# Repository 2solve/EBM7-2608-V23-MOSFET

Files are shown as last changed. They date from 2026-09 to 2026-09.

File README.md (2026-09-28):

# IC2S EBM7-2608 V2.3 — variante configurável 0-10 V / 4-20 mA (MOSFET)

Placa de extensão da família IC2S (Extension Board Model 7) com **quatro entradas analógicas configuráveis por software**
(cada uma em 0-10 V **ou** 4-20 mA), **uma entrada de célula de carga** e **um NTC de junta fria**, medidos por um ADC
sigma-delta de 24 bits (**AD7124-8**). Encaixa por baixo na base board: **P1** é o barramento (24 V, 5 V, SPI) e **P2** leva os
sinais de campo.

É a irmã da variante fixa 4-20 mA (repositório `2solve/EBM7-2608-V3`): mesma placa, mesmo layout de base, mais um MOSFET por
canal para escolher o modo e uma protecção completa da alimentação dos sensores.

Projecto KiCad 10 (testado em 10.0.5). Abrir
`Desenvolvimento_IC2S-EBM7-2608-V2.3-MOSFET/Projeto_IC2S-EBM7-2608-V2.3-MOSFET/IC2S-EBM7-2608-V2.3-MOSFET.kicad_pro`.

Identificador desta versão: **`IC2S-EBM7-2608-V2.3-MOSFET`**.

---

## Estado (28-09-2026)

| Verificação | Resultado |
|---|---|
| ERC | 0 erros |
| DRC (`--severity-all --schematic-parity`) | **0 erros**, 67 avisos (serigrafia) |
| Ligações por fazer | **48** |
| Paridade esquemático ↔ PCB | **1** (C35, ver [Pendentes](#pendentes)) |

**O esquemático está fechado; a placa não.** A PCB foi construída sobre a da variante fixa: as 148 peças comuns estão na mesma
posição e com as mesmas pistas; as **20 peças que só existem nesta variante** estão juntas num rectângulo à direita da placa,
à espera de serem colocadas e roteadas. Por isso as pastas de fabricação estão vazias.

---

## Estrutura do repositório

Padrão de pastas dos produtos da 2Solve (o mesmo de `Produtos/Axcel_Sensor`):

```
Desenvolvimento_IC2S-EBM7-2608-V2.3-MOSFET/
├── Projeto_IC2S-EBM7-2608-V2.3-MOSFET/
│   ├── IC2S-EBM7-2608-V2.3-MOSFET.kicad_pro / .kicad_sch / .kicad_pcb / .kicad_dru
│   ├── 01_conectores … 08_ntc.kicad_sch          (as oito folhas)
│   ├── footprints/EBM7_V23.pretty, symbols/       (bibliotecas locais, por ${KIPRJMOD})
│   ├── Documentos_de_Referência-…/                (33 datasheets + catálogo TDK de MLCC)
│   └── Outputs/drc_report.json
├── Documentos_IC2S-EBM7-2608-V2.3-MOSFET/
│   ├── 00-Especificações_Técnicas_…/   registos das alterações (25-09 e 28-09)
│   ├── 01-Esquemáticos_…/              Schematic-….pdf, ….step, …-Top_View.pdf, …-Bottom_View.pdf
│   ├── 02-Pinout_…/                    (vazio)
│   └── 03-Diagrama_Blocos_…/           (vazio)
└── Arquivos_Fabricação_IC2S-EBM7-2608-V2.3-MOSFET/
    ├── 00-Gerbers_…/  01-BOM_List_…/  02-Pick-and-Place_…/  03-Stencil_…/   (vazios até a placa estar roteada)
```

**Onde está cada decisão:** cada folha tem um bloco «DECISOES DESTA FOLHA» com notas numeradas; aqui cita-se *folha N, nota M*.

---

## O que é igual à variante fixa

Os blocos seguintes são os mesmos da fixa (lá estão explicados em detalhe); aqui só as referências, que mudam entre projectos:

| Bloco | Nesta placa |
|---|---|
| Entrada 24 V | **ramo único** (28-09-2026, folha 2, nota 13): TVS **D200** SMA6J33A-Q (clamp real 53,3 V) → fusível **F1** CC12H750MA → díodo **D5** MBR1H100SF → +24V_ADC; **C13** 10 µF/100 V na entrada do U3 (Recom p.4 pede 3,3 µF/100 V se Vin > 50 V) |
| Massas | GND_24V fundido em GND_ADC (folha 2, nota 7); DGND é a massa do processador |
| Alimentação | **U3** R-78HB5.0 (+24V_ADC → 5 V), **U4** SPX3819 (+3.3V_ANA), **U8** SPX3819 (+3.3V do lado PLC; era MCP1824 até 28-09), **U14** TL431 que grampeia o +3.3V_ANA a ~3,6 V (folha 3, nota 14) |
| Barreira | **U5** ISO7141: separação de ruído, não isolamento (folha 4, nota 1); regra de 1,0 mm e keepouts no PCB |
| ADC | **U6** AD7124-8, referência **U7** ADR4525 2,5 V no REFIN2 (folha 5, nota 1) |
| Protector dos laços | **U9-U12** TPS26613, +Vs a 12 V de **U15** TPS7A4001 (folha 6, notas 9 e 16) |
| Célula | **H1**: 1-2 = 2,5 V, 3-4 = 5 V (omissão), 5-6 = 3,3 V; **D31** Schottky RB162MM-60; **R5** 68 Ω 1 W (folha 7, notas 15 e 16) |
| NTC | junta fria para termopar (folha 8) |

---

## O que muda: modo duplo por canal

Decisão da folha 6: caixa **«DECISAO 25-09-2026 - MODO DUPLO»** e nota 12. Firmware: folha 5, nota 10.

Cada canal tem **dois caminhos** no P2:

- **Alimentação do sensor** (pino par, `+24V_AINn`): +24V_ADC → fusível **F3-F6** (125 mA) → díodo **D32-D35**
  (MBR1H100SF) → borne, com o TVS **D13/D16/D19/D22** (SMBJ51A) junto ao conector.
- **Sinal** (pino ímpar, `AINn`): borne → TVS 824500301 → **TPS26613** → divisor **40k2 / 10k** (sempre ligado) e, em
  paralelo, **burden 100 Ω** comutado pelo MOSFET → ferrite → RC → clamps BAV199 → ADC.

| Modo | MOSFET (Q1-Q4, FDN337N) | O que o sinal vê | No ADC |
|---|---|---|---|
| **4-20 mA** | fechado (GPIO = 1) | 100 Ω ‖ 50,2 kΩ = 99,8 Ω → 2,00 V a 20 mA | tap 0,080-0,398 V, ganho 4, fim de escala 31,4 mA |
| **0-10 V** | aberto (GPIO = 0) | 50,2 kΩ de entrada | tap 1,99 V a 10 V, ganho 1, gama garantida 0,5-12,5 V |

- A porta de cada MOSFET é comandada por uma **saída digital do próprio AD7124** (P1-P4 = pinos 6-9), com 100 kΩ a GND. No
  arranque a porta está em 0: o canal começa em 0-10 V; com um transmissor 4-20 mA ligado há hiccup até o firmware
  configurar o modo (folha 6, nota 13).
- **D26-D29** (MMSZ4702, zener de 15 V) protegem o dreno do MOSFET contra os surtos do campo.
- Verificações (na caixa da folha 6): nota (2) da Tabela 8-2 do TPS26613 cumprida mesmo a 40 mA (3,99 V < 4,46 V); FDN337N
  com RDS(on) ≤ 0,082 Ω a 2,5 V (0,08 % da carga, vai na calibração); zener não conduz em serviço (corte do OUT a 12,3 V).
- **Limitação:** abaixo de 0,5 V, em 0-10 V, o ADC com buffer e ganho 1 sai da especificação (AVSS + 0,1 V). Alternativa
  avaliada e **não aplicada** (muda o firmware): divisor 90k9/10k com ganho 2 em 0-10 V e ganho 8 em 4-20 mA.

**Mapa de canais** (da netlist):

| Canal de campo (P2) | Entrada do ADC | Saída que comanda o modo |
|---|---|---|
| AIN1 (P2.7) | AIN0 (pino 4) | P4 (pino 9) → MODO_AIN1 → Q1 |
| AIN2 (P2.9) | AIN1 (pino 5) | P3 (pino 8) → MODO_AIN2 → Q2 |
| AIN3 (P2.11) | AIN7 (pino 11) | P2 (pino 7) → MODO_AIN3 → Q3 |
| AIN4 (P2.13) | AIN6 (pino 10) | P1 (pino 6) → MODO_AIN4 → Q4 |
| Célula +/− | AIN10 / AIN11 | — |

## O que muda: protecção da alimentação dos sensores

Folha 6, nota 1, e folha 2, nota 9. Na variante fixa o fusível fica entre dois sumidouros de corrente (os condensadores do
bus e o TVS do borne) e um surto forte abre-o. Aqui:

- o **díodo em série** (D32-D35) impede que um surto do campo volte para o bus;
- o **SMBJ51A** (V_BR ≥ 56,7 V) não conduz nos surtos do bus, porque o TVS de entrada D200 grampeia a ≤ 53,3 V;
- assim a corrente de clamp **nunca passa pelo fusível**. Custo: ~0,5 V de queda na alimentação do sensor.

## Alterações de 28-09-2026 (reunião)

| O quê | Porquê |
|---|---|
| **Ramo único de 24 V**: saem F2, D1 e C1; F1 + D5 alimentam o U3 e o +24V_ADC; +24V_REG deixa de existir | reunião: é tudo alimentado pelos mesmos 24 V, não eram canais independentes nem isolados; ganha-se espaço |
| 100 nF fora do 24 V → TDK C1608X7R1H104K080AA (50 V), 24 peças; o C6 (+24V_ADC) fica GRM188R72A104KA35D (100 V) | 100 V estava sobredimensionado; pior caso fora do 24 V é o +12V_TPS a 31,7 V, por isso 50 V e não 25 V |
| 1 µF → TDK C1608X7R1H105K080AB (50 V) nos quatro | havia dois MPN para a mesma função |
| U8 MCP1824ST (SOT-223) → SPX3819 (SOT-23-5); faltam rotear as ligações do U8 e do C61 (2,2 µF na saída, como a V2.2) | mesmo MPN do U4 (`alteracao_LDO_3V3_lado_PLC_2026-09-28.md`) |

Condensadores: folha 2, nota 14. O catálogo TDK usado está em `Documentos_de_Referência-…/TDK_mlcc_commercial_general_en.pdf`
(p.34 para o 100 nF, p.35 para o 1 µF).

## Outras diferenças

- **C56 = 10 µF / 100 V em 1210** (GRM32EC72A106ME05L): condensador de entrada do U15 junto ao pino (SBVS162B pede > 1 µF
  efectivo).
- Footprint do **U15** conforme o land pattern da TI (SBVS162B p.22), com excepção dos pads NC no `.kicad_dru`.

---

## Placa (PCB)

- 60 × 60 mm, 4 camadas: F.Cu sinal · In1/In2 planos de massa partidos (DGND | GND_ADC) · B.Cu sinal e massa.
- Colocação, pistas, vias, zonas e keepouts das 148 peças comuns copiados da variante fixa (25-09-2026). 50 pistas da fixa
  **não** foram copiadas porque aqui dariam curto (saídas de F3-F6 antes do díodo; pinos do ADC que passaram a ser GPIO).

---

## Notas do esquemático desactualizadas

- **Folha 6, notas 13 e 14:** dizem AO3400A e BZT52H-C15; as peças montadas são **FDN337N** e **MMSZ4702T1G** (verificadas
  contra os datasheets na caixa «DECISAO 25-09»).
- **Folha 3, nota 1:** diz U3 = K78U05; a peça é o **R-78HB5.0-0.5L**.
- **Folha 7, nota 11:** diz TPS7A2025 para o U13; a peça montada é o **LP5907MFX-2.5**.

---

## Documentos

Em `Documentos_…/00-Especificações_Técnicas_IC2S-EBM7-2608-V2.3-MOSFET/`:

| Ficheiro | Conteúdo |
|---|---|
| `alteracoes_esquematico_e_PCB_2026-09-25.md` | registo das alterações de 25-09: modo duplo reposto, correcções vindas da fixa, verificação do FDN337N/MMSZ4702, importação e colocação da PCB |
| `alteracoes_reuniao_2026-09-28.md` | revisão da reunião de 28-09: ramo único de 24 V, entrada do R-78HB, tensão dos 100 nF, MPN do 1 µF |

---

## Pendentes

- **Paridade C35:** o pad 2 do C35 está ligado por pista a +3.3V_ANA (via em 162,25; 84,65 → pad), mas no esquemático é
  GND_ADC (é o condensador de filtro de AIN5 para a massa). Corrigir a pista na PCB.
- **Colocar as 20 peças** do rectângulo «SO CONFIGURAVEL» (fila = canal) junto de cada TPS26613 e do seu fusível, e **rotear
  as 48 ligações** que faltam.
- Serigrafia (67 avisos).
- Gerar Gerbers, BOM, pick-and-place e stencil quando a placa estiver roteada.
- Datasheets em falta: SMBJ51A-13-F (Diodes), MBR1H100SFT3G (onsemi), BLM18PG471SN1D (Murata), LED KG EELP41.22,
  resistências genéricas.
- Revisão independente do roteamento (`2shw-pcb:check-roteamento`) antes de fabricar.
- O mecanismo da avaria em campo da V2.2 não foi medido (G8).

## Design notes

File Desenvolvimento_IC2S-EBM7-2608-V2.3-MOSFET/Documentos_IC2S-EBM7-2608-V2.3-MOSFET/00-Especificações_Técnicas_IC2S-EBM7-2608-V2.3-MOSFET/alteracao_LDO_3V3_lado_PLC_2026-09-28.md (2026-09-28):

# Regulador de 3,3 V do lado PLC — U8: MCP1824ST-3302E/DB → SPX3819M5-L-3-3/TR (2026-09-28)

Da reunião de 25-09: «esse chip é mais caro… existe regulador menores». O U8 alimenta só o lado 1 do ISO7141 (+5V do P1 → 3,3 V, massa DGND).

## Comparação que decidiu (datasheets locais; preços da API Mouser gravados nos repositórios)

| | MCP1824ST-3302E/DB (saiu) | SPX3819M5-L-3-3/TR | MCP1824T-3302E/OT |
|---|---|---|---|
| Encapsulamento | SOT-223-3 | SOT-23-5 | SOT-23-5 |
| Entrada (operação / máx. absoluto) | 2,1-6,0 V / 6,5 V | 2,5-16 V / 20 V | 2,1-6,0 V / 6,5 V |
| Precisão em temperatura | ±2,5 % | ±2 % | ±2,5 % |
| Estável com cerâmico | sim, «Stable with 1.0 µF Ceramic» (DS22070A p.1) | **não especificado** («bench testing», SPX3819 rev. 2.0.5 p.7); provado em campo na V2.2 | sim (mesmo datasheet) |
| ESD HBM | ≥ 4 kV | 1 kV | ≥ 4 kV |
| Mouser 1 un. | 0,64 USD (25-09) | 0,51 USD (16-09) | 0,56 USD (25-09) |
| Stock Mouser | 11 898 (25-09) | **99** (16-09) | 14 500 (25-09) |

Carga real: só o lado 1 do ISO7141, ≤ 8 mA a 40 Mbps (TI SLLSE83F p.10). O ISO7141 pede VCC1 de 2,7 a 5,5 V
(p.5) e 0,1 µF a ≤ 2 mm do pino (p.22 e p.25): cumprido com qualquer um dos três (C a 1,9 mm).

**Critério da equipa (28-09-2026): menos MPN, mais peças do mesmo tipo.** Na EBM7 o SPX3819 já é o U3/U4 do
+3.3V_ANA; na EBM2 o MCP1824T já é o U4 do 3V3_REF. O MCP1824ST sai das três placas.

## O que mudou

- **U8 = SPX3819M5-L-3-3/TR**, SOT-23-5. Ligações: 1 IN e 3 EN a +5V, 2 GND a DGND, 4 BYP aberto, 5 OUT a +3.3V.
- Condensadores mantidos (os que já estavam na entrada e na saída).
- PCB: pegada SOT-23-5 no mesmo sitio; 11 pistas e 2 restos tirados. **Faltam rotear 6 ligações do U8** (além das 48 que já faltavam).

## Verificação

- ERC 0 erros; DRC 0 erros, paridade 1 (C35, anterior); netlist: só mudam os pinos do U8.

## Riscos em aberto

- **Estabilidade com cerâmico não garantida no datasheet** do SPX3819; a base é a experiência de campo da V2.2 (SPX3819 do +3.3V_ANA só com cerâmicos). Aqui a carga é ≤ 8 mA, o que joga a favor (p.7), mas não foi medido. Medir na 1.ª placa: 3,3 V em DC e, com osciloscópio emprestado, o ripple na saída.
- **Stock Mouser baixo** (99 un. a 16-09): confirmar antes da compra (LCSC tem).
- ESD 1 kV HBM (entrada no +5V do P1, conector interno: só conta no manuseio).
- Preços e stock são das consultas gravadas (16 e 25-09), não de hoje: a web da Mouser bloqueia leitura automática.

## Complemento: circuito recomendado do datasheet (SPX3819 rev. 2.0.5, Fig. 18 «Standard Application Circuit», p.8)

| Elemento | Datasheet | Na placa |
|---|---|---|
| EN | alto (> 2 V); «ENABLE may be tied directly to VIN» | EN directo a +5V ✅ |
| BYP | condensador «(Opt.)»; pode ficar aberto se o ruído não importa (p.7) | aberto ✅ |
| Entrada | medido com CIN = 1 µF (p.2-3) | 10 µF cerâmico ✅ |
| Saída | desenhado polarizado; 2,2 µF electrolítico ou 1 µF tântalo (p.7) | C48 10 µF + C23 100 nF + **C61 2,2 µF**, todos cerâmicos |

**C61 = 2,2 µF C1608X5R1E225K080AB** (MPN já na BOM) acrescentado em paralelo à saída do U8, para a saída ficar como a do SPX3819 da V2.2 em campo (2,2 µF + 10 µF + 100 nF, só cerâmicos; a V2.2 não tinha nenhum electrolítico junto do SPX3819: os únicos eram C5/C11 de 100 µF nos +24V_ADC dos PDM2). No PCB: clone da pegada do C48, a 3 mm do U8, **2 ligações por rotear**. ERC 0; DRC 0 erros, sem avisos novos.

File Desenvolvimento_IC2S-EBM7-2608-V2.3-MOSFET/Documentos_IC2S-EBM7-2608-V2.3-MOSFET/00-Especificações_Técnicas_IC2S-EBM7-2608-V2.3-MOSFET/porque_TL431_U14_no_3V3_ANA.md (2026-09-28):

# Porque existe o U14 (TL431B) no +3.3V_ANA

Pergunta da reunião de 25-09-2026: *«o SPX3819 já regula os 3,3 V; para que serve o TL431?»*

## Resposta curta

O U4 (SPX3819) **só consegue fornecer corrente, não a absorver**. O U14 existe para o caso contrário: quando entra
corrente **de fora** no +3.3V_ANA e empurra o rail para cima. Quem a mete lá são os díodos de protecção das entradas.
Sem o U14, essa corrente não tem para onde ir e o rail sobe até queimar o ADC. Em funcionamento normal o U14 está
desligado e não faz nada.

## O caminho da corrente, passo a passo

1. Cada entrada analógica do ADC tem um **BAV199** (D11, D12, D15, D18, D21, D24, D30): um díodo para o GND_ADC e outro para o **+3.3V_ANA**.
2. Se a tensão numa entrada passar de ~3,3 V + 0,6 V (surto no cabo, sensor ligado mal, 24 V no borne errado), o díodo
   de cima conduz e **despeja a corrente no +3.3V_ANA**. É exactamente para isso que ele lá está: proteger o pino do ADC,
   que aguenta no máximo **AVDD + 0,3 V** (AD7124-8 Rev. F, p.14, *Analog Input Voltage to AVSS*).
3. Essa corrente tem de sair do rail por algum lado. O SPX3819 é um LDO série: o transístor de saída liga a entrada à
   saída e só puxa corrente **da entrada para a saída**. Não há no datasheet (MaxLinear SPX3819 Rev. 2.0.5) nenhuma
   especificação de corrente absorvida na saída: ele simplesmente corta.
4. Sem o U14, a corrente só pode ir para o consumo das cargas (ADC, referência, alguns mA) e para os condensadores do
   rail, que carregam. Se o surto trouxer mais corrente do que as cargas gastam, **o rail sobe**. A revisão kicad-happy
   (folha 3, nota 14) estimou que chegava a ~10 V.
5. O AVDD do AD7124 tem **máximo absoluto de 3,96 V** (p.14, *AVDD to AVSS*). A 10 V o ADC morre, e com ele a
   referência U7 e o que mais estiver no rail.

O U14 fecha esse caminho: com o rail acima de ~3,6 V ele conduz e absorve a corrente para o GND_ADC, segurando o rail.

## Os números

O U14 é um regulador *shunt*: conduz quando a tensão no pino REF passa de V_ref. O divisor R47 4k42 / R48 10k faz o
limiar ser V_ref × (1 + 4,42/10) = V_ref × 1,442.

| Grandeza | Valor | Fonte |
|---|---|---|
| V_ref (TL431B) | 2,440 / 2,495 / 2,550 V (mín / típ / máx) | TI SLVS543S, p.6 |
| Limiar do clamp | **3,52 / 3,60 / 3,68 V** | 1,442 × V_ref |
| Com 100 mA a atravessar | +0,07 V (\|Z_KA\| ≤ 0,5 Ω × 1,442) → até ~3,75-3,79 V | SLVS543S p.6; folha 3, nota 14 |
| Saída do SPX3819 | 3,3 V ± 2 % em temperatura → **3,37 V no máximo** | SPX3819 p.2 |
| Folga entre os dois | 3,52 − 3,37 = **0,15 V**: em serviço o U14 nunca conduz | — |
| AVDD máx. absoluto do AD7124 | **3,96 V** | AD7124-8 p.14 |
| Folga do clamp ao máx. absoluto | 3,96 − 3,79 = 0,17 V no pior caso | — |
| Corrente que o U14 aguenta | 100 mA recomendado, 150 mA máx. absoluto | SLVS543S p.5 |
| Corrente residual estimada de um surto | 12-23 mA (corrida 4) | folha 3, nota 14 |
| Consumo permanente do divisor | 3,3 V / 14,42 kΩ = **0,23 mA** | — |
| Fuga do U14 desligado | ≤ 1 µA | SLVS543S p.6, I_off |

## Porque não outra peça

- **Zener de 3,6 V** (ZMM5227B, da mesma série do D4 já usado; Diodes DS30024 Rev. C-2, p.2): V_Z = **3,42-3,78 V a
  20 mA**, Z_ZT = 24 Ω a 20 mA e Z_ZK = **1700 Ω a 0,25 mA**. Dois problemas:
  - joelho mole: com 1700 Ω perto do joelho, o zener já conduz a 3,3-3,37 V e carrega o LDO permanentemente. A fuga
    só está especificada a 1 V (≤ 15 µA), não a 3,3 V;
  - clamp alto: a 100 mA fica em ~3,78 + 0,08 A × 24 Ω ≈ **5,7 V**, bem acima dos 3,96 V do ADC.
  O TL431B tem joelho abrupto (≤ 1 µA desligado), Z_KA ≤ 0,5 Ω e 0,5 % de tolerância.
- **TVS de 3,3 V**: o mesmo problema, maior. Os TVS de baixa tensão têm fuga alta e clamp muito acima do standoff.
- **Não pôr nada e confiar no LDO**: é o caso descrito acima. O LDO não absorve corrente.
- **Custo**: o TL431BQDBZR custa ~0,44 USD à unidade (Mouser, BOM da EBM2 de 25-09) e o divisor são duas
  resistências 0603.

## Resumo para o revisor

| | Sem o U14 | Com o U14 |
|---|---|---|
| Serviço normal | 3,3 V | 3,3 V (o U14 está desligado; gasta 0,23 mA no divisor) |
| Surto numa entrada | o BAV199 despeja no rail, o LDO não absorve, o rail sobe (~10 V) e o ADC morre | o U14 absorve até 100 mA e o rail fica ≤ 3,79 V, abaixo dos 3,96 V do ADC |

O mesmo raciocínio está resumido na **folha 3, nota 14** do esquemático. A EBM2 V5 tem o mesmo circuito (U3, folha 3,
nota 7), com o limiar a 3,52 V.

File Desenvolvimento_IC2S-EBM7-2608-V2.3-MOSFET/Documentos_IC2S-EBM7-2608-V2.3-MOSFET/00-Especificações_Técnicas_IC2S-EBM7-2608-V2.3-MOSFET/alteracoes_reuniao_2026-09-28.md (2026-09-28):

# Alterações de 28-09-2026 — revisão da reunião

Quatro observações da reunião, aplicadas ao esquemático e ao PCB. Notas no esquemático: **folha 2, notas 2, 13 e 14**.

## 1. Ramo único de 24 V

**Antes:** depois do TVS havia dois ramos iguais, F1 → D5 → +24V_REG (só o U3, R-78HB) e F2 → D1 → +24V_ADC (laços,
LDO de 12 V, LED), cada um com o seu 10 µF / 100 V.

**Agora:** saem **F2, D1 e C1**. F1 → D5 → **+24V_ADC** alimenta tudo; o nome +24V_REG deixa de existir.

- Motivo (equipa): é tudo alimentado pelos mesmos 24 V; os ramos não eram canais independentes nem isolados; ganha-se espaço.
- Corrente: 116 mA em regime, ~180 mA em falha (folha 1, nota 2) contra F1 = 750 mA e D5 = MBR1H100SF 1 A.
- Arranque: ~30 µF a jusante do F1; pela escala da nota 10 (3,4 mA²s para 20 µF) dá ~5 mA²s contra 150 mA²s de fusão:
  **~29× de margem** (era ~44× no ramo com 20 µF). Estimativa, não medida.
- Custo: perde-se a selectividade. Um curto no +24V_ADC abre F1 e desliga a placa inteira (antes só o ramo dos laços).

PCB: saíram as três peças, a pista do ânodo (Net-(D1-A)), a ligação do díodo à diagonal e o toco de GND do condensador. O bus
+24V passa a acabar no pad 1 do F1. A pista do C13 desce em F.Cu (139,80; 127,20 → 128,80) e junta-se, a 45°, à diagonal
que já ia para a via do +24V_ADC em (141,20; 130,10). Largura 0,50 mm (classe Power24). No `.kicad_pro` saíram os padrões
de netclass `+24V_REG` e `Net-(D1-A)`.

## 2. Condensador de entrada do R-78HB

**C13 = 10 µF / 100 V, 1210 (GRM32EC72A106ME05L)**, a 5,5 mm do pino Vin. Recom R-78HB-0.5 (rev. 5-2019), p.4: *«To
protect the converter during power-up, use C1 = 3.3 µF/100V if Vin > 50V»*. Operamos a 24 V, mas o clamp do TVS é 53,3 V,
portanto aplica-se — e 10 µF / 100 V cumpre. A capacidade de saída (~50 µF) está abaixo do máximo de 100 µF (p.2). O
1 µF / 100 V da p.6 é da configuração de saída negativa, que não é a nossa. **Sem alteração.**

## 3. Tensão dos 100 nF

Todos os 25 eram GRM188R72A104KA35D (100 V). Só um precisa: o **C6**, no +24V_ADC (até 53,3 V).

| Grupo | Tensão máxima | Peça |
|---|---|---|
| C6 no +24V_ADC | 53,3 V (clamp) | fica GRM188R72A104KA35D, 100 V — valor `100nF/100V` |
| 4 no +12V_TPS | 12 V; 31,7 V com o divisor do LDO em falha (folha 6, nota 17) | **TDK C1608X7R1H104K080AA, 50 V** |
| 20 em 3,3 V, 5 V, ADC e referência | ≤ 5 V | **TDK C1608X7R1H104K080AA, 50 V** (um só MPN) |

25 V não serve: não cobre os 31,7 V do +12V_TPS. Fonte: catálogo TDK *MLCC commercial general*, p.34 (X7R, 1608,
100 nF ±10 %, DC 50 V). Valor escrito `100nF/50V`. São 24 peças.

## 4. Mesmo MPN para a mesma função

- 10 µF nos rails de 2,5 / 3,3 / 5 V: já era um só MPN (0603YD106KAT2A). Sem alteração.
- 2,2 µF, 22 µF e 10 µF / 100 V (1210): um MPN cada. Sem alteração.
- **1 µF: havia dois** (885012206002 em 1 e C0603C105K4RACTU em 3). Agora os quatro são **TDK C1608X7R1H105K080AB**
  (X7R, 1608, 1 µF ±10 %, DC 50 V; catálogo TDK p.35). Valor escrito `1uF/50V` (antes havia `1uF` e `1uF/16V`).

O catálogo TDK está em `Projeto_…/Documentos_de_Referência-…/TDK_mlcc_commercial_general_en.pdf`.

## Verificação

- Netlist antes/depois: só saem F2, D1, C1 e a rede Net-(D1-A); C13 / D5 / U3 passam de +24V_REG a +24V_ADC; 28 condensadores
  mudam de valor/MPN. Nenhuma outra ligação muda.
- ERC: 0 erros (os avisos são os mesmos de antes).
- DRC (`--severity-all --schematic-parity --all-track-errors`): 0 erros, 67 avisos (serigrafia), 48 por ligar e paridade 1 (C35) — os mesmos de antes, das peças só desta variante.
- PDF do esquemático, vistas, STEP e drc_report.json regenerados; a fabricação continua vazia (placa por rotear).

Scripts (sessão de 28-09): `sch_2809.py` (esquemático), `pcb_2809.py` (PCB), `pro_2809.py` (netclasses).

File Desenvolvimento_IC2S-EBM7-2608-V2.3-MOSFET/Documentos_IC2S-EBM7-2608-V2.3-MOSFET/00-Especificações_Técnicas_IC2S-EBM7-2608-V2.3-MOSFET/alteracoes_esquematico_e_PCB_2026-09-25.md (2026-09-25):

# Alteração 25-09-2026 — esquemático do sem_trilhas alinhado com a legacy + modo duplo reposto

Pedido de Javier Rivadineira (25-09-2026): levar ao esquemático do sem_trilhas as correcções da legacy e redimensionar o que o
MOSFET (selecção 0-10 V / 4-20 mA) exigir. PCB, biblioteca de footprints, regras e keepout ficam para a fase seguinte.

## Achado que motivou o redimensionamento

A decisão de 21-09 (carga de 110 R, só 4-20 mA) tinha sido aplicada também ao sem_trilhas: R27-R30 = 0 R e R31-R34 = 110 R.
Com isso o sem_trilhas tinha 110 R permanentes no OUT de cada TPS26613, em paralelo com o 100 R comutado pelo MOSFET:
em 0-10 V a entrada puxava 10 V / 110 Ω = 91 mA (o TPS26613 limita a 25-40 mA, SLVSFE3C p.5) — modo 0-10 V impossível.
O divisor original do modo duplo (nota 12 da folha 6, 2026-09-04) estava no backup `06_lacos.kicad_sch.antes_carga` (18-09):
R27-R30 = 40k2, R31-R34 = 10k.

## Alterações (folhas 01, 02, 06)

| Folha | Alteração |
|---|---|
| 01 | `#PWR0102` (P1.19) GND_24V → GND_ADC; nota 3 |
| 02 | `#PWR0202/0206/0209` GND_24V → GND_ADC (D200.2, C1.2, T7); **R200 removido** com os 2 fios; `#FLG0204` + `#PWR0210` + fio + 2 junções (PWR_FLAG redundante) removidos; T7 → `TP_GND_ADC_P1`; notas 6, 7, 12 e ERC |
| 06 | R27-R30 0R → **40k2 `RG1608P-4022-B-T5`**; R31-R34 110R → **10k `RG1608P-103-B-T5`**; C56 100 nF 0603 → **10 µF/100 V 1210 `GRM32EC72A106ME05L`** (CIN local do U15, como o C34 da legacy); texto "DECISAO 21-09" substituído por "DECISAO 25-09" (modo duplo); notas 14, 16, 17 |

MPN: `RG1608P-4022-B-T5` derivado do sistema de numeração Susumu (catálogo RG p.17: E-96 com 4 dígitos, P = ±25 ppm, B = 0,1 %);
substitui o `ERA-3AEB4022V` do backup, cujo datasheet não existe no projecto. `RG1608P-103-B-T5` e `GRM32EC72A106ME05L` já verificados.

## Dimensionamento (valores calculados)

| Grandeza | Valor | Limite / fonte | Veredicto |
|---|---|---|---|
| k do divisor | 10/50,2 = 0,1992 | — | — |
| Carga 4-20 (Q fechado) | 100 ‖ 50,2 k = 99,8 Ω | — | — |
| V(OUT) a 20 mA | 2,00 V | < 4,46 V (SLVSFE3C Tab. 8-2 nota 2, p.20) | ok |
| V(OUT) a IOL máx 40 mA | 3,99 V | < 4,46 V (IOL p.5) | ok |
| Tap 4-20 mA | 0,080-0,398 V | ganho > 1: ≥ AVSS−0,05 V (AD7124 rev.F p.7) | ok |
| Fim de escala ganho 4 | 31,4 mA | — | — |
| 0-10 V (Q aberto) | 50,2 kΩ; tap 1,99 V a 10 V | ganho 1 buffer: ≥ AVSS+0,1 V (p.7) → gama 0,50-12,5 V | 0-0,5 V fora de spec (já documentado, nota 13) |
| Filtro anti-aliasing | 8,0 k + 3k3, 100 nF → 141 Hz | — | — |
| Burden 20 mA | 40 mW | RG1608 0,1 W (Susumu p.18) | ok |
| Gate | VOH ≥ AVDD−0,6 = 2,7 V | AD7124 p.8 | depende do MOSFET |

## Verificação

- ERC sem_trilhas: 331 → 328 avisos, 0 erros; nenhum aviso novo (saem 3 `lib_symbol_issues` das peças removidas).
- Netlist: 169 → 168 componentes (sai R200); mudam só C56, R27-R34 e T7; pinos que mudam: C1.2, D200.2, P1.19, T7.1 (GND_24V → GND_ADC); a rede GND_24V deixa de existir.
- Texto renderizado (PDF do kicad-cli): movido 12 mm para a direita, já não sobrepõe o rótulo do C50.
- Backups: `01_conectores/02_entrada/06_lacos.kicad_sch.antes_sync_legacy`.
- Legacy: 2 linhas órfãs da nota 7 da folha 2 corrigidas (backup `02_entrada.kicad_sch.antes_notas_gnd`); ERC legacy 301, 0 erros.

## Pendentes

- **Q1-Q4 FDN337N e D26-D29 MMSZ4702T1G sem datasheet** no projecto (onsemi bloqueia descargas). As notas 13/14 decidiram
  AO3400A e BZT52H-C15, que têm PDF local. Falta confirmar RDS(on) a VGS 2,7 V, pinagem SOT-23 e fuga do zener a 12,3 V.
- **Opção a avaliar:** k = 0,1 (90k9/10k) com ganho 2 em 0-10 V e ganho 8 em 4-20 mA fecha a gama 0-0,5 V (ganho > 1 aceita
  AVSS−0,05 V). Muda o firmware.
- Fase PCB: footprint HVSSOP corrigido, C56 em 1210, zonas GND_24V, `.kicad_dru`, classes de rede, keepout do P1; a paridade
  vai acusar os valores e o footprint novos até se actualizar a PCB a partir do esquemático.

## Adenda — FDN337N e MMSZ4702T1G verificados (datasheets entregues pelo Javier)

`FDN337N-D.PDF` (onsemi Rev.5) e `MMSZ4678T1-D.PDF` (Rev.13) em `Documentos_de_Referência`.

| Verificação | Datasheet | Circuito | Veredicto |
|---|---|---|---|
| VDSS | 30 V (p.1) | dreno ≤ ~16,4 V em surto (zener) | ok, 1,8× |
| VGS máx | ±8 V (p.1) | GPIO do AD7124 ≤ AVDD 3,3 V | ok |
| VGS(th) | 0,4-1,0 V (p.2) | 0 V desligado (100k), ≥ 2,7 V ligado | ok |
| RDS(on) | ≤ 0,082 Ω a VGS 2,5 V (p.2); 125 °C ≈ ×1,7 | em série com 100 Ω | 0,08-0,14 %, vai na calibração |
| IDSS | ≤ 1 µA a 24 V; 10 µA a 55 °C (p.2) | só carrega a fonte 0-10 V | desprezável |
| Pinagem FDN337N | não numerada no PDF Rev.5 | footprint 1=G, 2=S, 3=D | ok, confirmada pelo Javier (25-09) |
| Land pattern | recomendação p.5 com pads maiores que os 0,6 × 1,475 do footprint | — | menor, fase PCB |
| VZ MMSZ4702 | 14,25-15,75 V (p.3) | OUT corta a 12,3 V | não conduz em serviço |
| IR | ≤ 0,05 µA a 11,4 V (p.3) | 0-10 V | desprezável |
| Polaridade | pino 1 = cátodo (p.1) | D26 pad 1 = BRD_AIN1, pad 2 = GND_ADC | ok |
| Surto | ZZT ≈ 2 Ω a 20 mA (Fig.5); Fig.4 ≈ 50 W a 0,3 ms | ~0,32 A, ~5 W de pico (48,4 V herdado da nota 13) | ok (extrapolação, critério D) |

Nota da folha 6 ("POR CONFIRMAR") reescrita com estes números; ERC 328, 0 erros. Backup `06_lacos.kicad_sch.antes_nota_mosfet`.
Incidente: a primeira escrita juntou as linhas com "n" em vez de `\n`; detectado no render, reposto do backup e reescrito.

## PCB do sem_trilhas importada do esquemático e colocada como na legacy (25-09-2026)

Pedido do Javier: se o esquemático estiver pronto, importar para a PCB e colocar os componentes como na legacy.
Pré-verificação: BOM do sem_trilhas = legacy + só selecção de modo (4 FDN337N, 4 MMSZ4702T1G, 4×100k, 4×100R, divisor
40k2/10k) + protecção de laços (4 MBR1H100SF, SMBJ51A em vez de SMBJ36A).

Correspondência pelo UUID do símbolo: os 148 footprints da legacy existem no sem_trilhas; contorno idêntico.
Script `st_pcb_sync.py` (cópia em scratch, verificação, depois cópia para o projecto):

| Passo | Resultado |
|---|---|
| Pistas/vias antigas | 114 apagadas (ficariam inválidas com a colocação nova) |
| R200 | removido (não está no esquemático) |
| 148 footprints comuns | posição, rotação, lado e campos iguais à legacy |
| U15, C56, P1, P2 | footprint copiado da legacy (pads TI do HVSSOP, C56 em 1210, courtyard ±1,52 dos conectores = biblioteca) |
| Valores/MPN | R27-R30 40k2 RG1608P-4022-B-T5, R31-R34 10k RG1608P-103-B-T5, T7 TP_GND_ADC_P1, U5 MPN do esquemático |
| Redes | 7 pads alterados; GND_24V desaparece |
| Zonas | as 11 da legacy (GND_ADC/DGND ×3, keepouts ISO7141, P1, Fid1-3) |
| 20 peças só do sem_trilhas | aparcadas fora do contorno, fila por canal: x 186 / 191,5 / 197 / 202,5 / 208 = 100R / FDN337N / MMSZ4702 / 100k / MBR1H100SF; y 86 / 96 / 106 / 116 = canal 1-4 |
| `.kicad_pro` | classe DIGSIDE; 90 padrões (por nome, por pads nos 6 nomes que mudam, por função nas redes novas: BRD_AINn e Net-(D32..35-A) em Loop, Net-(U12-OUT) em Loop) |
| `.kicad_dru` | novo: barreira_PLC_campo e U15_pads_NC (U12 na legacy) |
| Biblioteca | HVSSOP-8-1EP.kicad_mod da legacy (pads TI) |

Verificação independente (segundo método): 148/148 footprints e 444/444 pads na mesma posição da legacy, mesmos tamanhos e
camadas; 20 extras fora do contorno; zonas iguais (nome, vértices, rede).
No projecto: DRC 67 avisos de serigrafia, 0 erros, 336 por ligar (sem pistas), paridade 0; ERC 328 avisos, 0 erros.
Backups: `.kicad_pcb.antes_import_pcb`, `.kicad_pro.antes_import_pcb`, `footprints/HVSSOP-8-1EP.kicad_mod.antes_import_pcb`.

Pendente: colocar as 20 peças aparcadas (cada canal junto ao seu TPS26613 e ao seu fusível) e rotear; as 740 pistas da legacy
não foram copiadas (os laços são diferentes).

## Vias e pistas de massa copiadas da fixo_420 (25-09-2026)

Pedido do Javier: as zonas GND da configuravel não tinham o mesmo que a fixo_420. As zonas eram iguais (nome, vértices, rede)
e estavam cheias, mas sem nenhuma via/pista de GND_ADC e DGND (apagadas na importação). Copiadas as 233 da fixo_420
(78 vias: 69 GND_ADC + 9 DGND; 155 pistas), cada uma verificada contra os pads da configuravel: 0 tocam um pad de outra rede.
DRC no projecto: 0 erros, 67 avisos de serigrafia, paridade 0; por ligar 336 → 231; os 12 pendentes de GND_ADC são todos de
peças aparcadas fora da placa. Backup `.kicad_pcb.antes_gnd_vias`.

## Roteamento da fixo_420 copiado; ordem do H1 portada (25-09-2026)

Javier: "as áreas de GND estão erradas, copia como na 420". As zonas eram idênticas (definição linha a linha), mas o
enchimento diferia porque a configuravel não tinha o roteamento de sinal (furos das vias, pistas em B.Cu). Render das 3
camadas de massa lado a lado confirmou.

**Achado no caminho:** a folha 7 da fixo_420 teve duas revisões a 22-09 (`antes_ordem` 11:03, `antes_ordem2` 11:42) que
reordenaram o H1 — 1-2 +2V5_EXC, 3-4 +5V_ADC (omissão), 5-6 +3.3V_ANA — e que não tinham passado para a configuravel
(ficara 1-2 +5V_ADC, 3-4 +3.3V_ANA, 5-6 +2V5_EXC). Comparação pad a pad das duas placas: só 13 pads diferem — F3-F6.2 (díodo
em série, intencional), U6 pinos 5-10 (P1-P4 como GPIO do modo duplo, intencional) e H1.2/4/6 (esta falha). Portado à folha 7
(etiquetas, fios e nota 15 iguais à fixo_420; render comparado); ERC 328, 0 erros, só mudam H1.2/4/6. Backup
`07_celula.kicad_sch.antes_h1_ordem`.

Roteamento: 61 redes copiadas inteiras (550 itens) quando todos os pads caem numa só rede e nenhum item toca pad de outra;
as 10 redes que diferem (+24V_AIN1-4, AIN1-6_ADC) copiadas item a item e podadas pelo DRC (troço exacto por posição e
comprimento). Resultado: 690 pistas e 136 vias (fixo_420: 740 e 136). DRC 0 erros, 67 avisos de serigrafia, paridade 0;
por ligar 50 = 40 das 20 peças aparcadas + 6 fan-outs do U6 + 4 P2↔TVS (dependem de onde ficar o díodo). Backup
`.kicad_pcb.antes_rota_420`.

## PCB reconstruída a partir da fixo_420 (proposta do Javier, 25-09-2026)

"Copiar as posições e pistas dos componentes usados na 420 e na configurável; deixar fora, juntos numa área, os que só
existem na configurável." Método `st_rebase.py`: base = PCB da fixo_420 inteira. Nos 148 footprints comuns (mesmo UUID)
muda só a identidade (referência, valor, MPN e restantes campos, folha) e as redes dos pads (69), a partir da netlist da
configuravel. Pistas/vias: mantidas as 826 da fixo_420 cuja geometria já estava na configuravel depurada; removidas 50
(as que curto-circuitariam: saídas de F3-F6 antes do díodo, fan-out dos pinos GPIO do U6). As 20 peças só da configuravel:
dentro de um rectângulo em User.Drawings (182,5;81,5)-(211,5;117,0), fila = canal, com legenda.
Verificação: 148/148 footprints com conteúdo (geometria, serigrafia, textos) igual à fixo_420; zonas 11 = 11; vias 136 = 136.
DRC no projecto: 0 erros, 65 avisos (serigrafia), paridade 0, por ligar 50 (40 das peças por colocar + 10 a rotear).
Motivo: na versão anterior os textos ${REFERENCE} internos de 9 footprints ficavam os da configuravel (só os campos tinham
sido copiados). Backup `.kicad_pcb.antes_rebase`.

## Estrutura de pastas (25-09-2026)

Projecto antigo da raiz de `EBM7-2608-V23_configuravel` (placement de 16-17/09, 504 ficheiros) apagado a pedido do Javier;
cópia zip em scratch `out/configuravel_raiz_antiga_2026-09-25.zip`. O Javier subiu o conteúdo de `sem_trilhas` para a raiz e
apagou a subpasta. Conferido: mesma estrutura que a fixo_420 (projecto na raiz + footprints/ symbols/ .history/);
PCB e folhas = últimas versões (KiCad regravou: 1 padrão de netclass duplicado removido; retoque do Javier em +5V_ADC perto
de (133,8;114,6)). DRC 0 erros, 65 avisos de serigrafia, paridade 0, 50 por ligar; ERC 328, 0 erros.

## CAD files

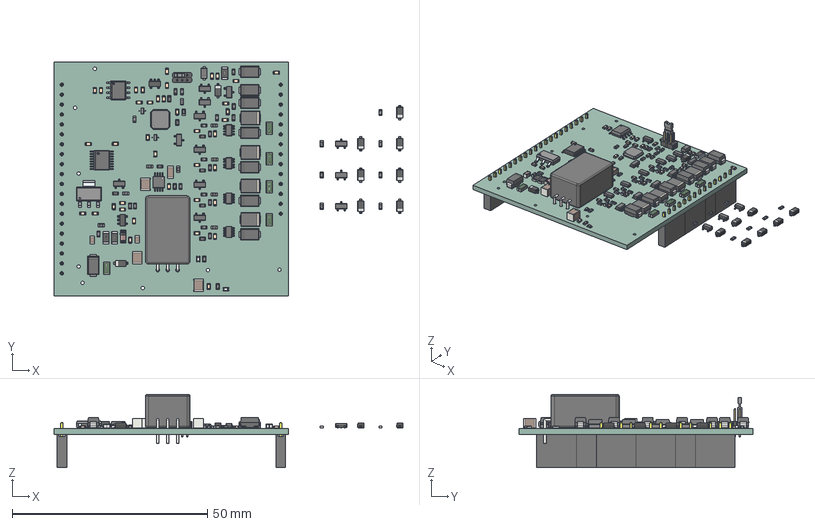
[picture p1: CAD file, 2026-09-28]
Desenvolvimento_IC2S-EBM7-2608-V2.3-MOSFET/Documentos_IC2S-EBM7-2608-V2.3-MOSFET/01-Esquemáticos_IC2S-EBM7-2608-V2.3-MOSFET/IC2S-EBM7-2608-V2.3-MOSFET.step
89.3 x 60.0 x 18.7 mm
User Library-CAPC1608X___ x 39
User Library-RESC1608X___ x 40
MSOP-8-1EP_3x3mm_P0.65mm_EP1.68x1.88mm
C_1210_3225Metric x 3
User Library-so8-3
User Library-S1G-1 x 8
20493694-5DF9-4F19-89F9-3D9FA7465B40 x 9
D_SMB x 4
C_1206_3216Metric
C_0805_2012Metric x 2
User Library-MAX_QSOP16
User Library-SMD RESISTOR-1 x 3
User Library-FUSER_nanoSMD x 5
User Library-SOT-23-3_body_1 x 8
User Library-SOT-23-3_pin_SOT_SOT-23_1 x 24
User Library-Murata_NFM18PS_Murata_NFM_body x 2
User Library-Murata_NFM18PS_Murata_NFM_terminals x 2
User Library-LED_0603_WS_Pocket002 x 2
User Library-LED_0603_WS_Pad004 x 2
User Library-LED_0603_WS_Fillet x 2
User Library-LED_0603_WS_Pocket001 x 2
User Library-LED_0603_WS_Pad x 2
User Library-FB_1608_Pad001 x 7
User Library-FB_1608_Cut x 7
9360D52E-9BD1-42F0-84E8-DD68B45C04DC
BDA441D8-A5C4-4C44-A8A0-E9EBD450C16B x 2
Converter_DCDC_RECOM_R_78HB_05L_THT
PinsArrayL
FilletPinR
SOT-23 x 4
SOT-23-8 x 4
D_SOD_123F
K÷rper2 x 3
Pin2 x 3
User Library-SOD80-2
User Library-ZL262-4SG x 9
IC2S-EBM7-2608-V2.3-MOSFET_PCB

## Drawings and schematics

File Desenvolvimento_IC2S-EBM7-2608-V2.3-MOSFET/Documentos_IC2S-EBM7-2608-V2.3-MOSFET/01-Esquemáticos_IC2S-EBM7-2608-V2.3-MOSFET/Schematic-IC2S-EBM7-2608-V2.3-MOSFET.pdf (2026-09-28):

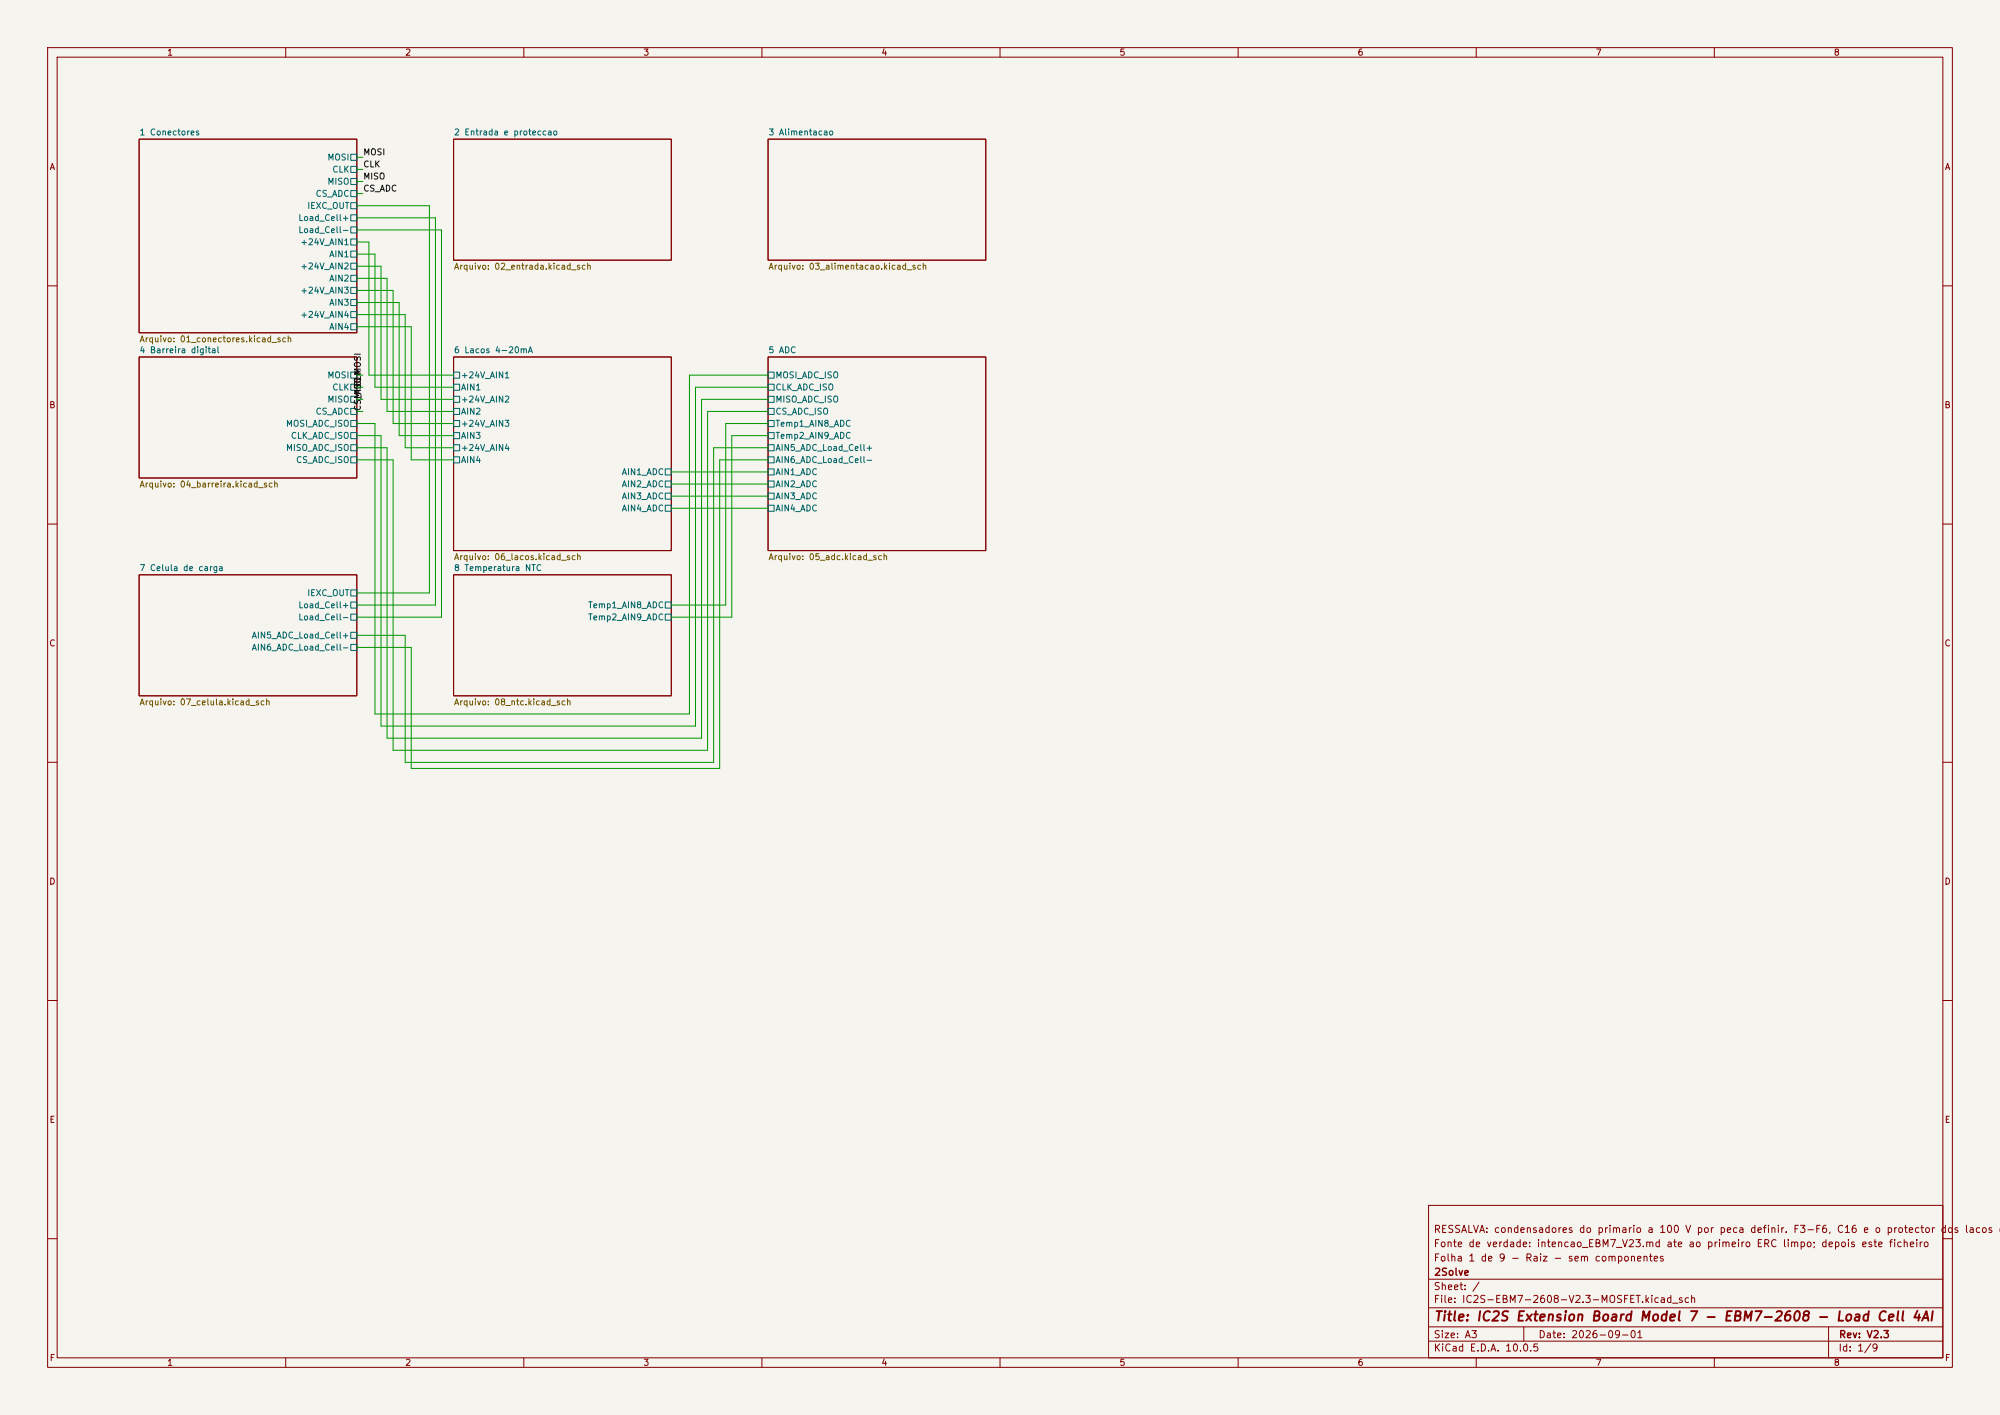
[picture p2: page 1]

Arquivo: 03_alimentacao.kicad_sch CLK MOSI CS_ADC MISO

RESSALVA: condensadores do primario a 100 V por peca definir. F3-F6, C16 e o protector dos lacos escolhidos (2026-09-03).
Fonte de verdade: intencao_EBM7_V23.md ate ao primeiro ERC limpo; depois este ficheiro
Folha 1 de 9 - Raiz - sem componentes
2Solve
Sheet: /
File: IC2S-EBM7-2608-V2.3-MOSFET.kicad_sch
Title: IC2S Extension Board Model 7 - EBM7-2608 - Load Cell 4AI

Size: A3 | Rev: V2.3 | F Date: 2026-09-01
KiCad E.D.A. 10.0.5 | Id: 1/9

1 | 2 | 3 | 4 | 5 | 6

AB

C

D

AB

C

### D Date: 2026-09-01

Size: A4 | Rev: V2.3

## Title: IC2S Extension Board Model 7 - EBM7-2608 - Load Cell 4AI

### File: 01_conectores.kicad_sch

### Sheet: /1 Conectores/

2Solve

### Folha 2 de 9 - 1 Conectores

### Fonte de verdade: intencao_EBM7_V23.md ate ao primeiro ERC limpo; depois este ficheiro

Fid2 | Fid3 | RESSALVA: condensadores do primario a 100 V por peca definir. F3-F6, C16 e o protector dos lacos escolhidos (2026-09-03). GND_ADC

GND_ADC

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
# 14 P2 M20-7821446 +24V DGND

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
20 P1 M20-7822046 +5V DGND

GND_ADC

DGND

Fid1 | +24V_AIN4 +24V_AIN3 AIN2

AIN1 +24V_AIN1

+24V_AIN2

AIN4

CLK

# AIN3 CS_ADC

IEXC_OUT Load_Cell+

Load_Cell-

MISO MOSI LDAC_DAC

# CS_DAC USB1 USB2

SCL

# ID3 CS4

ID1

SDA | 6. Fiduciais sem pino electrico: as redes unconnected-(FidX) 5. P2 = M20-7821446 (campo): IEXC e celula > folha 7; da V2.2 desaparecem do diff de netlist. a espera dessas folhas (aviso de ERC temporario esperado). lacos 4-20 mA > folha 6. Os pinos de hoja na raiz ficam
2. P1-20 leva 116 mA em regime (4 lacos a 24 mA, 2 LED, U3) e passiva real e a base board via P1. Fecha os 4 pendentes 3. PWR_FLAG de +24V, GND_ADC (P1.19), +5V e DGND nesta folha: a fonte Barramento da base board. Sinais nao usados nesta placa: 1. P1 = M20-7822046 (Harwin, FILA UNICA de 20 - nao 2x10). DECISOES DESTA FOLHA (F2 2.2b) ~180 mA em falha: 6% dos 3 A/contacto (Harwin M20), margem 16x. USB1/2, CS_DAC, LDAC_DAC, CS4, ID1, ID3, SDA, SCL -
de ERC das folhas 2 e 3. terminam aqui por desenho da familia de extensoes. +5V | 4. P1-18 e P2-1 sem ligacao (tambem na V2.2). DGND +24V | GND_ADC

AB

C

D

AB

C

### D Date: 2026-09-01

## Title: IC2S Extension Board Model 7 - EBM7-2608 - Load Cell 4AI

### File: 02_entrada.kicad_sch

### Sheet: /2 Entrada e proteccao/

2Solve

### Folha 3 de 9 - 2 Entrada e proteccao

### Fonte de verdade: intencao_EBM7_V23.md ate ao primeiro ERC limpo; depois este ficheiro

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

+24V | T1

TP_+24V

F1 CC12H750MA-TR GND_ADC

D200

SMA6J33A-Q

T7
TP_GND_ADC_P1 GND_ADC
D5 MBR1H100SF | C13 10uF/100V GND_ADC+24V_ADC

campo, que a intencao 4.6 ja mandava corrigir. CC12H750MA: 150 mA2s (Eaton 4309 p.2), 44x de margem; F3-F6 fundem 750x antes. 3,4 mA2s (R = 1,7 ohm) - 2,3x ACIMA: o mecanismo B da avaria em

C7 saem. As duas ramas eram iguais e F2/F7 so protegem a placa 11. RAMO UNICO +24V_ADC (proposta da equipa, 2026-09-04): F7, D3 e

(os cortos de campo param no TPS26613 e em F3-F6). 100 mA em

regime no D1 (PMEG6010CEH, 1 A); I2t de arranque igual ao de 10.

~90x o I2t do arranque com a propria resistencia - mecanismo B. clamp REAL 53,3 V @ 11,3 A (nao 40,6 - erro da biblioteca). 1. F1 = CC12H750MA-TR (Eaton, time-lag). I2t de fusao 150 mA2s, 2. F2 REMOVIDO 28-09-2026 (nota 13): ramo unico, F1 alimenta a placa toda. DECISOES DESTA FOLHA (F2 2.2b - fonte: intencao_EBM7_V23.md) Na V2.2 o pino 1 era o anodo; o diff de netlist mostra a permuta. Murata cat. 2021 p.110): MORNSUN Tab.1 p.3 pede C1 =

Folha 6: saem tambem C10, C12, T3, R2 e D4 (grupo lacos 3-4). 12. C1/C13 = GRM32EC72A106KE05 (1210 X7S 10 uF 100 V, 13. RAMO UNICO DE 24 V (reuniao da equipa, 2026-09-28): | de GND_ADC (era GND_24V). Escolha do projectista 2026-09-04. 10 uF/100 V ceramico junto ao Vin (C13); C1 e o bulk

saem F2, D1 e C1. Tudo vem dos mesmos 24 V: nao eram

canais independentes nem isolados. F1 + D5 alimentam

o U3 (R-78HB) e o +24V_ADC; +24V_REG deixa de existir. 116 mA em regime, ~180 mA em falha (folha 1, nota 2):

Arranque ~30 uF: ~5 mA2s (escala da nota 10) contra

F1 750 mA e D5 MBR1H100SF 1 A chegam. 150 mA2s do CC12H750MA, ~29x de margem. Perde-se a selectividade: curto no +24V_ADC abre F1. C13 = entrada do R-78HB: Recom R-78HB-0.5 p.4 pede
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

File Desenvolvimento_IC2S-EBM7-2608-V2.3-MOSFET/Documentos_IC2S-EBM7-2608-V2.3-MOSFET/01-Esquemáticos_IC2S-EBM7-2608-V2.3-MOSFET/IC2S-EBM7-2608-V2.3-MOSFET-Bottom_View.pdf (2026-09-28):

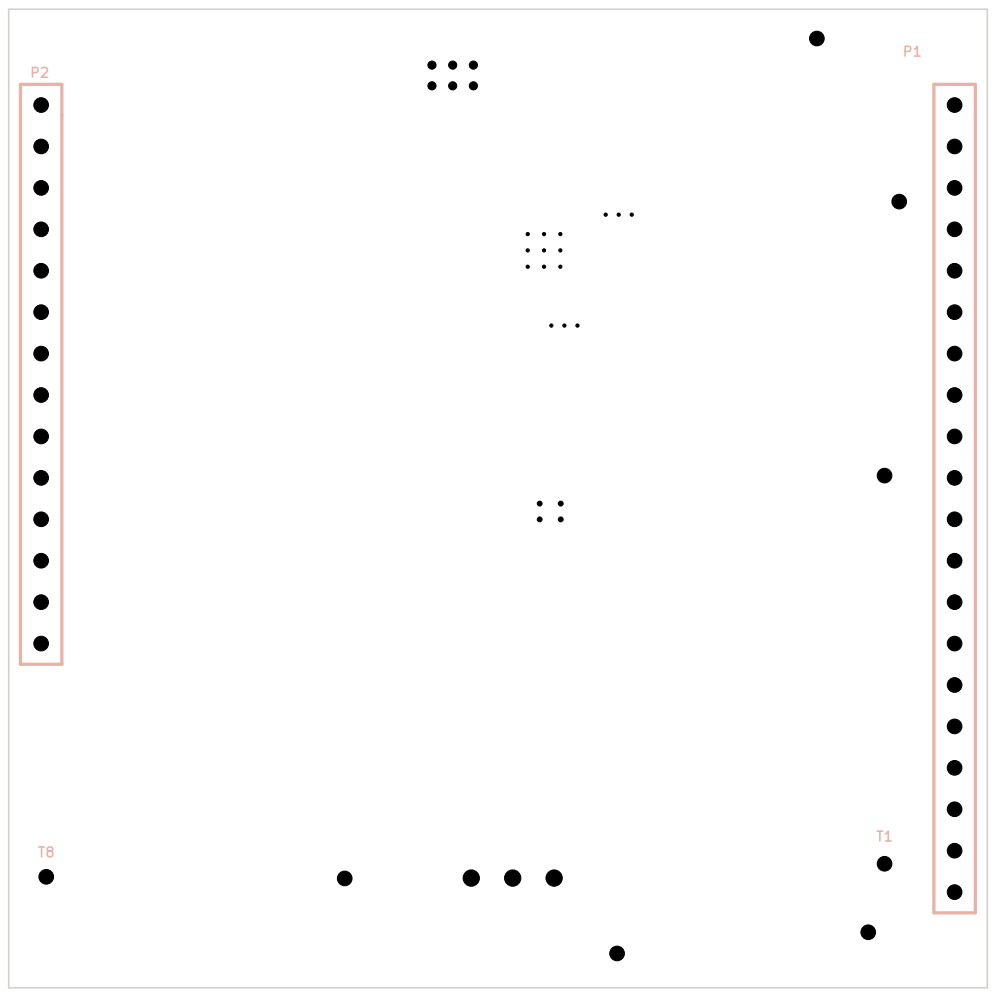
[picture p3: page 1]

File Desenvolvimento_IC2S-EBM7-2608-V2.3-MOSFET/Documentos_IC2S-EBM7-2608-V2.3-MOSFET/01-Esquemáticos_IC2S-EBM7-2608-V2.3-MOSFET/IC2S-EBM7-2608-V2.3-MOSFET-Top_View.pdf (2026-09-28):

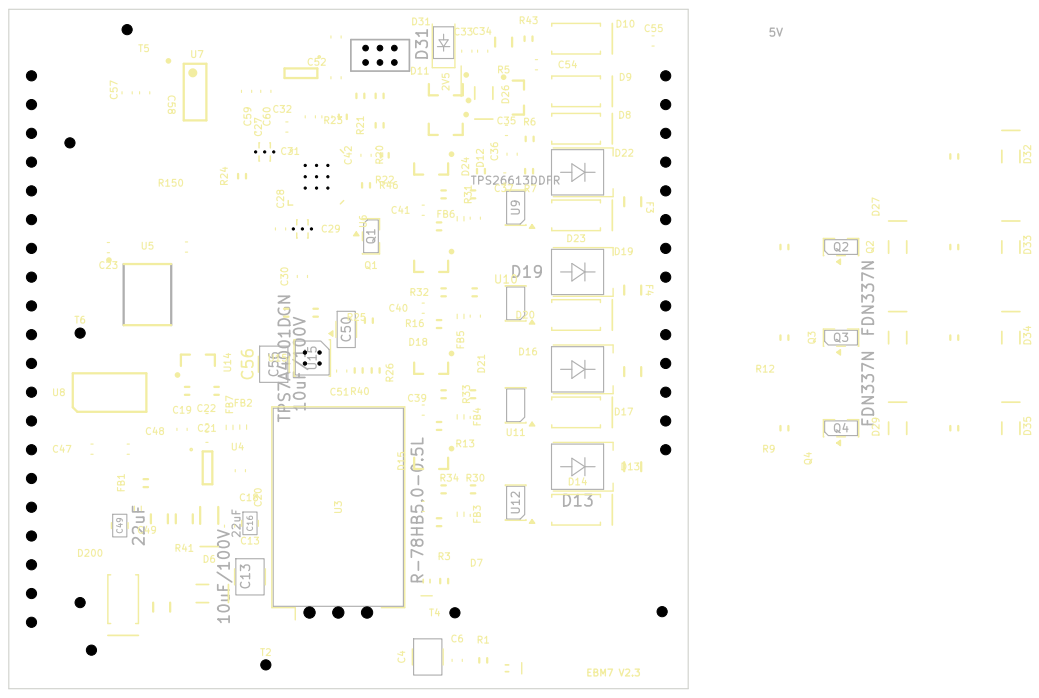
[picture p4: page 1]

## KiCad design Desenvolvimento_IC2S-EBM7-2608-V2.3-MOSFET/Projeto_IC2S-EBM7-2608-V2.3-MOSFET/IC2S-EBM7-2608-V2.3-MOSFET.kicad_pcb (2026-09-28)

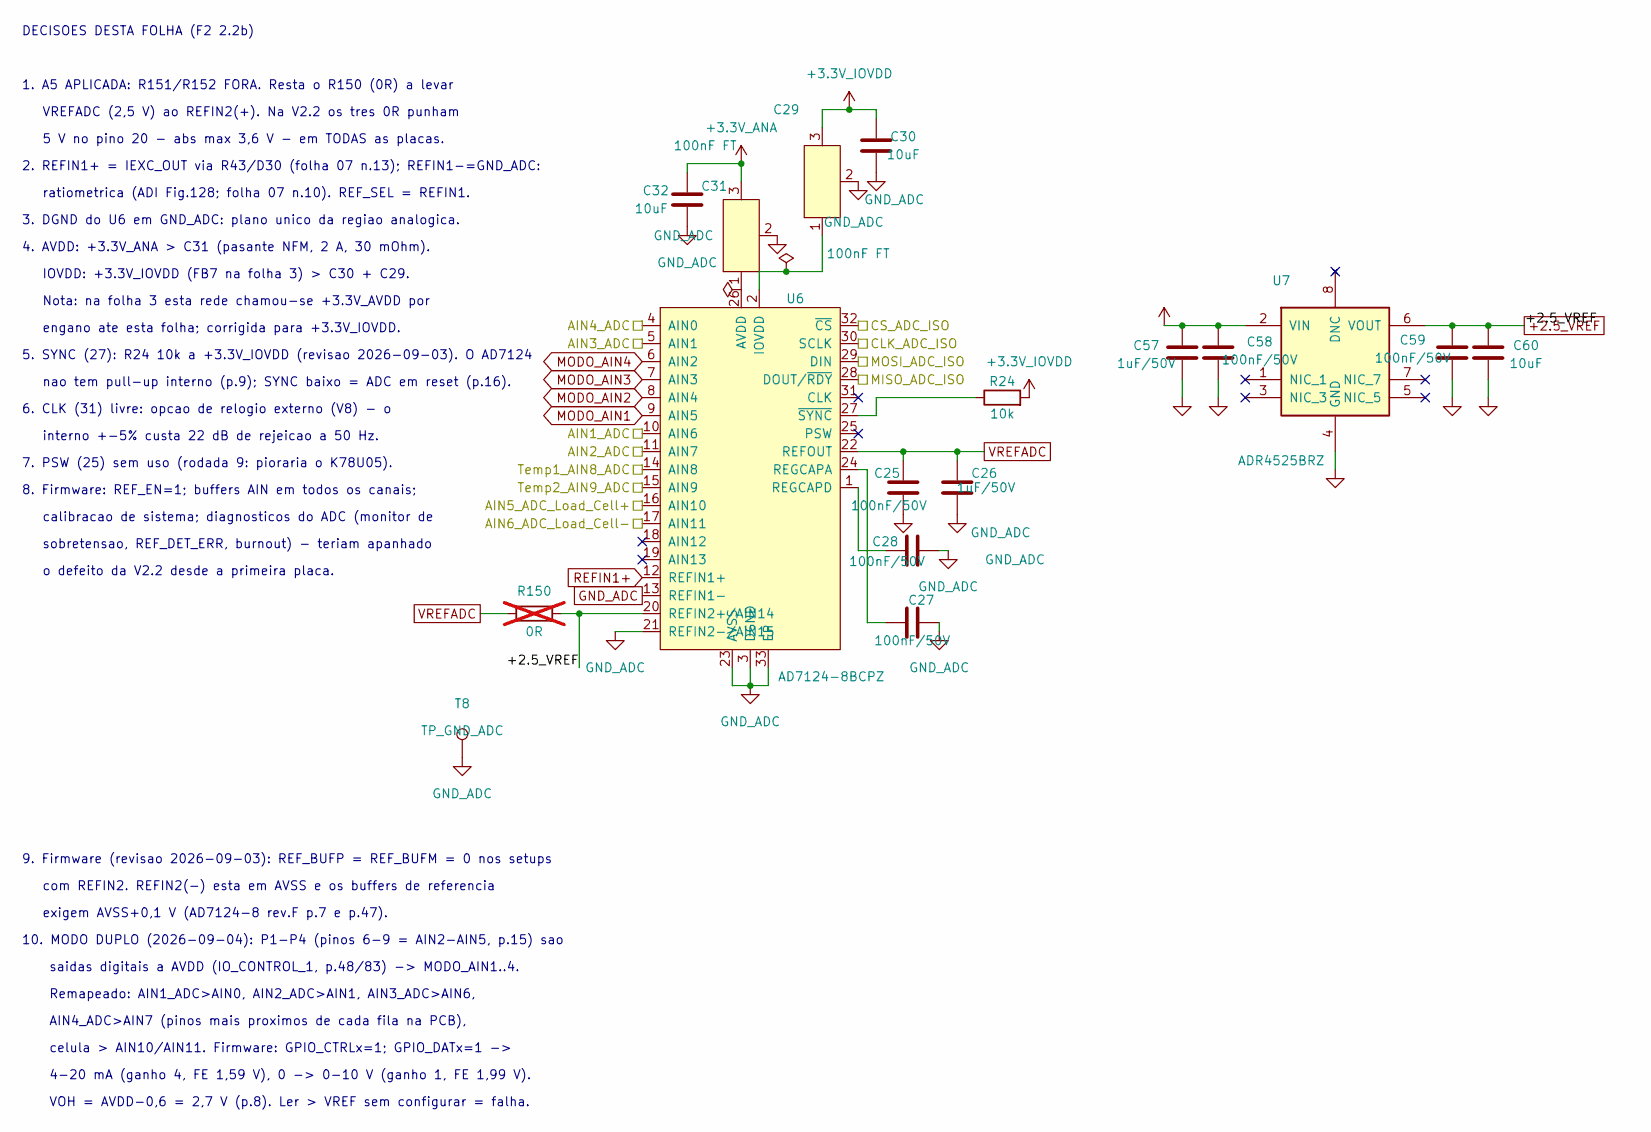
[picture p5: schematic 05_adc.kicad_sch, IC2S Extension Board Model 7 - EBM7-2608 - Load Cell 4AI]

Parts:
C25, C27, C28, C58, C59: 100nF/50V; 0603C; MPN C1608X7R1H104K080AA
C26, C57: 1uF/50V; 0603C; MPN C1608X7R1H105K080AB
C29, C31: 100nF FT; NFM0603; MPN NFM18PC104R1C3D
C30, C32, C60: 10uF; 0603C; MPN 0603YD106KAT2A
R24: 10k; 0603R; MPN RC0603FR-0710KL
R150: 0R; 0603R; MPN RC0603JR-070RL; not fitted
T8: TP_GND_ADC; TestPad_Via
U6: AD7124-8BCPZ; LFCSP-32-2; MPN AD7124-8BCPZ
U7: ADR4525BRZ; SOIC8; MPN ADR4525BRZ

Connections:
+2.5_VREF: C59.1, C60.1, R150.2, U6.20 (REFIN2+/AIN14), U7.6 (VOUT)
+3.3V_IOVDD: C29.3 (OUT), C30.2, R24.2; also elsewhere on the board
/4 Barreira digital/CLK_ADC_ISO: U6.30 (SCLK); also elsewhere on the board
/4 Barreira digital/CS_ADC_ISO: U6.32 (~CS); also elsewhere on the board
/4 Barreira digital/MISO_ADC_ISO: U6.28 (DOUT/~RDY); also elsewhere on the board
/4 Barreira digital/MOSI_ADC_ISO: U6.29 (DIN); also elsewhere on the board
/5 ADC/AIN1_ADC: U6.10 (AIN6); also elsewhere on the board
/5 ADC/AIN2_ADC: U6.11 (AIN7); also elsewhere on the board
/5 ADC/AIN3_ADC: U6.5 (AIN1); also elsewhere on the board
/5 ADC/AIN4_ADC: U6.4 (AIN0); also elsewhere on the board
/5 ADC/AIN5_ADC_Load_Cell+: U6.16 (AIN10); also elsewhere on the board
/5 ADC/AIN6_ADC_Load_Cell-: U6.17 (AIN11); also elsewhere on the board
/5 ADC/Temp1_AIN8_ADC: U6.14 (AIN8); also elsewhere on the board
/5 ADC/Temp2_AIN9_ADC: U6.15 (AIN9); also elsewhere on the board
MODO_AIN1: U6.9 (AIN5); also elsewhere on the board
MODO_AIN2: U6.8 (AIN4); also elsewhere on the board
MODO_AIN3: U6.7 (AIN3); also elsewhere on the board
MODO_AIN4: U6.6 (AIN2); also elsewhere on the board
unnamed: C29.1 (IN), U6.2 (IOVDD)
unnamed: C31.1 (IN), U6.26 (AVDD)
unnamed: C27.2, U6.24 (REGCAPA)
unnamed: C28.2, U6.1 (REGCAPD)
unnamed: R24.1, U6.27 (~SYNC)
REFIN1+: U6.12 (REFIN1+); also elsewhere on the board
VREFADC: C25.2, C26.1, R150.1, U6.22 (REFOUT); also elsewhere on the board

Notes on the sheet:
celula > AIN10/AIN11. Firmware: GPIO_CTRLx=1; GPIO_DATx=1 ->
ratiometrica (ADI Fig.128; folha 07 n.10). REF_SEL = REFIN1.
4. AVDD: +3.3V_ANA > C31 (pasante NFM, 2 A, 30 mOhm).
engano ate esta folha; corrigida para +3.3V_IOVDD.
Nota: na folha 3 esta rede chamou-se +3.3V_AVDD por
com REFIN2. REFIN2(-) esta em AVSS e os buffers de referencia
1. A5 APLICADA: R151/R152 FORA. Resta o R150 (0R) a levar
Remapeado: AIN1_ADC>AIN0, AIN2_ADC>AIN1, AIN3_ADC>AIN6,
calibracao de sistema; diagnosticos do ADC (monitor de
sobretensao, REF_DET_ERR, burnout) - teriam apanhado
saidas digitais a AVDD (IO_CONTROL_1, p.48/83) -> MODO_AIN1..4.
AIN4_ADC>AIN7 (pinos mais proximos de cada fila na PCB),
2. REFIN1+ = IEXC_OUT via R43/D30 (folha 07 n.13); REFIN1-=GND_ADC:
interno +-5% custa 22 dB de rejeicao a 50 Hz.
VREFADC (2,5 V) ao REFIN2(+). Na V2.2 os tres 0R punham
DECISOES DESTA FOLHA (F2 2.2b)
3. DGND do U6 em GND_ADC: plano unico da regiao analogica.
6. CLK (31) livre: opcao de relogio externo (V8) - o
10. MODO DUPLO (2026-09-04): P1-P4 (pinos 6-9 = AIN2-AIN5, p.15) sao
IOVDD: +3.3V_IOVDD (FB7 na folha 3) > C30 + C29.
o defeito da V2.2 desde a primeira placa.
nao tem pull-up interno (p.9); SYNC baixo = ADC em reset (p.16).
5. SYNC (27): R24 10k a +3.3V_IOVDD (revisao 2026-09-03). O AD7124
8. Firmware: REF_EN=1; buffers AIN em todos os canais;
VOH = AVDD-0,6 = 2,7 V (p.8). Ler > VREF sem configurar = falha.
7. PSW (25) sem uso (rodada 9: pioraria o K78U05).
5 V no pino 20 - abs max 3,6 V - em TODAS as placas.
exigem AVSS+0,1 V (AD7124-8 rev.F p.7 e p.47).
4-20 mA (ganho 4, FE 1,59 V), 0 -> 0-10 V (ganho 1, FE 1,99 V).
9. Firmware (revisao 2026-09-03): REF_BUFP = REF_BUFM = 0 nos setups

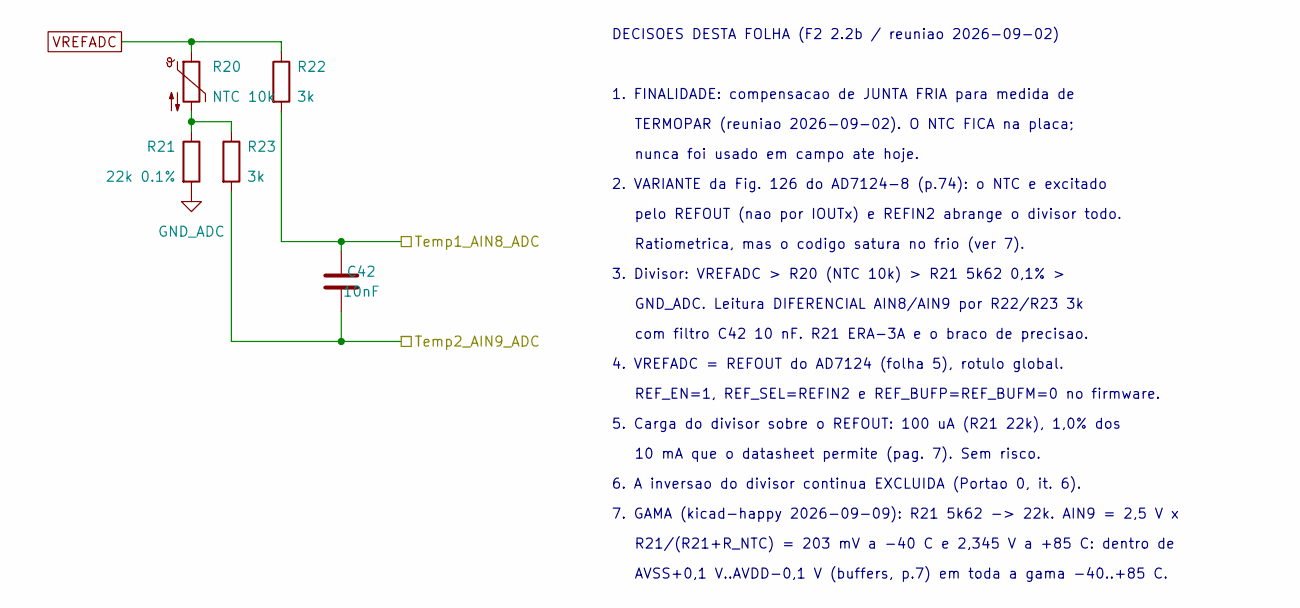
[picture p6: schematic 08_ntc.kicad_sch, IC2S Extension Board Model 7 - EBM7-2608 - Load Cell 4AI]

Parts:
C42: 10nF; 0603C; MPN GCM188R71H103KA37J
R20: NTC 10k; 0603R; MPN NTCS0603E3103JLT
R21: 22k 0.1%; 0603R; MPN RG1608P-223-B-T5
R22, R23: 3k; 0603R; MPN RC0603FR-073KL

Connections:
/5 ADC/Temp1_AIN8_ADC: C42.2, R22.2; also elsewhere on the board
/5 ADC/Temp2_AIN9_ADC: C42.1, R23.2; also elsewhere on the board
unnamed: R20.2, R21.1, R23.1
VREFADC: R20.1, R22.1; also elsewhere on the board

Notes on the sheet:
GND_ADC. Leitura DIFERENCIAL AIN8/AIN9 por R22/R23 3k
pelo REFOUT (nao por IOUTx) e REFIN2 abrange o divisor todo.
5. Carga do divisor sobre o REFOUT: 100 uA (R21 22k), 1,0% dos
Ratiometrica, mas o codigo satura no frio (ver 7).
4. VREFADC = REFOUT do AD7124 (folha 5), rotulo global.
nunca foi usado em campo ate hoje.
R21/(R21+R_NTC) = 203 mV a -40 C e 2,345 V a +85 C: dentro de
1. FINALIDADE: compensacao de JUNTA FRIA para medida de
2. VARIANTE da Fig. 126 do AD7124-8 (p.74): o NTC e excitado
REF_EN=1, REF_SEL=REFIN2 e REF_BUFP=REF_BUFM=0 no firmware.
10 mA que o datasheet permite (pag. 7). Sem risco.
3. Divisor: VREFADC > R20 (NTC 10k) > R21 5k62 0,1% >
DECISOES DESTA FOLHA (F2 2.2b / reuniao 2026-09-02)
6. A inversao do divisor continua EXCLUIDA (Portao 0, it. 6).
com filtro C42 10 nF. R21 ERA-3A e o braco de precisao.
TERMOPAR (reuniao 2026-09-02). O NTC FICA na placa;
7. GAMA (kicad-happy 2026-09-09): R21 5k62 -> 22k. AIN9 = 2,5 V x
AVSS+0,1 V..AVDD-0,1 V (buffers, p.7) em toda a gama -40..+85 C.

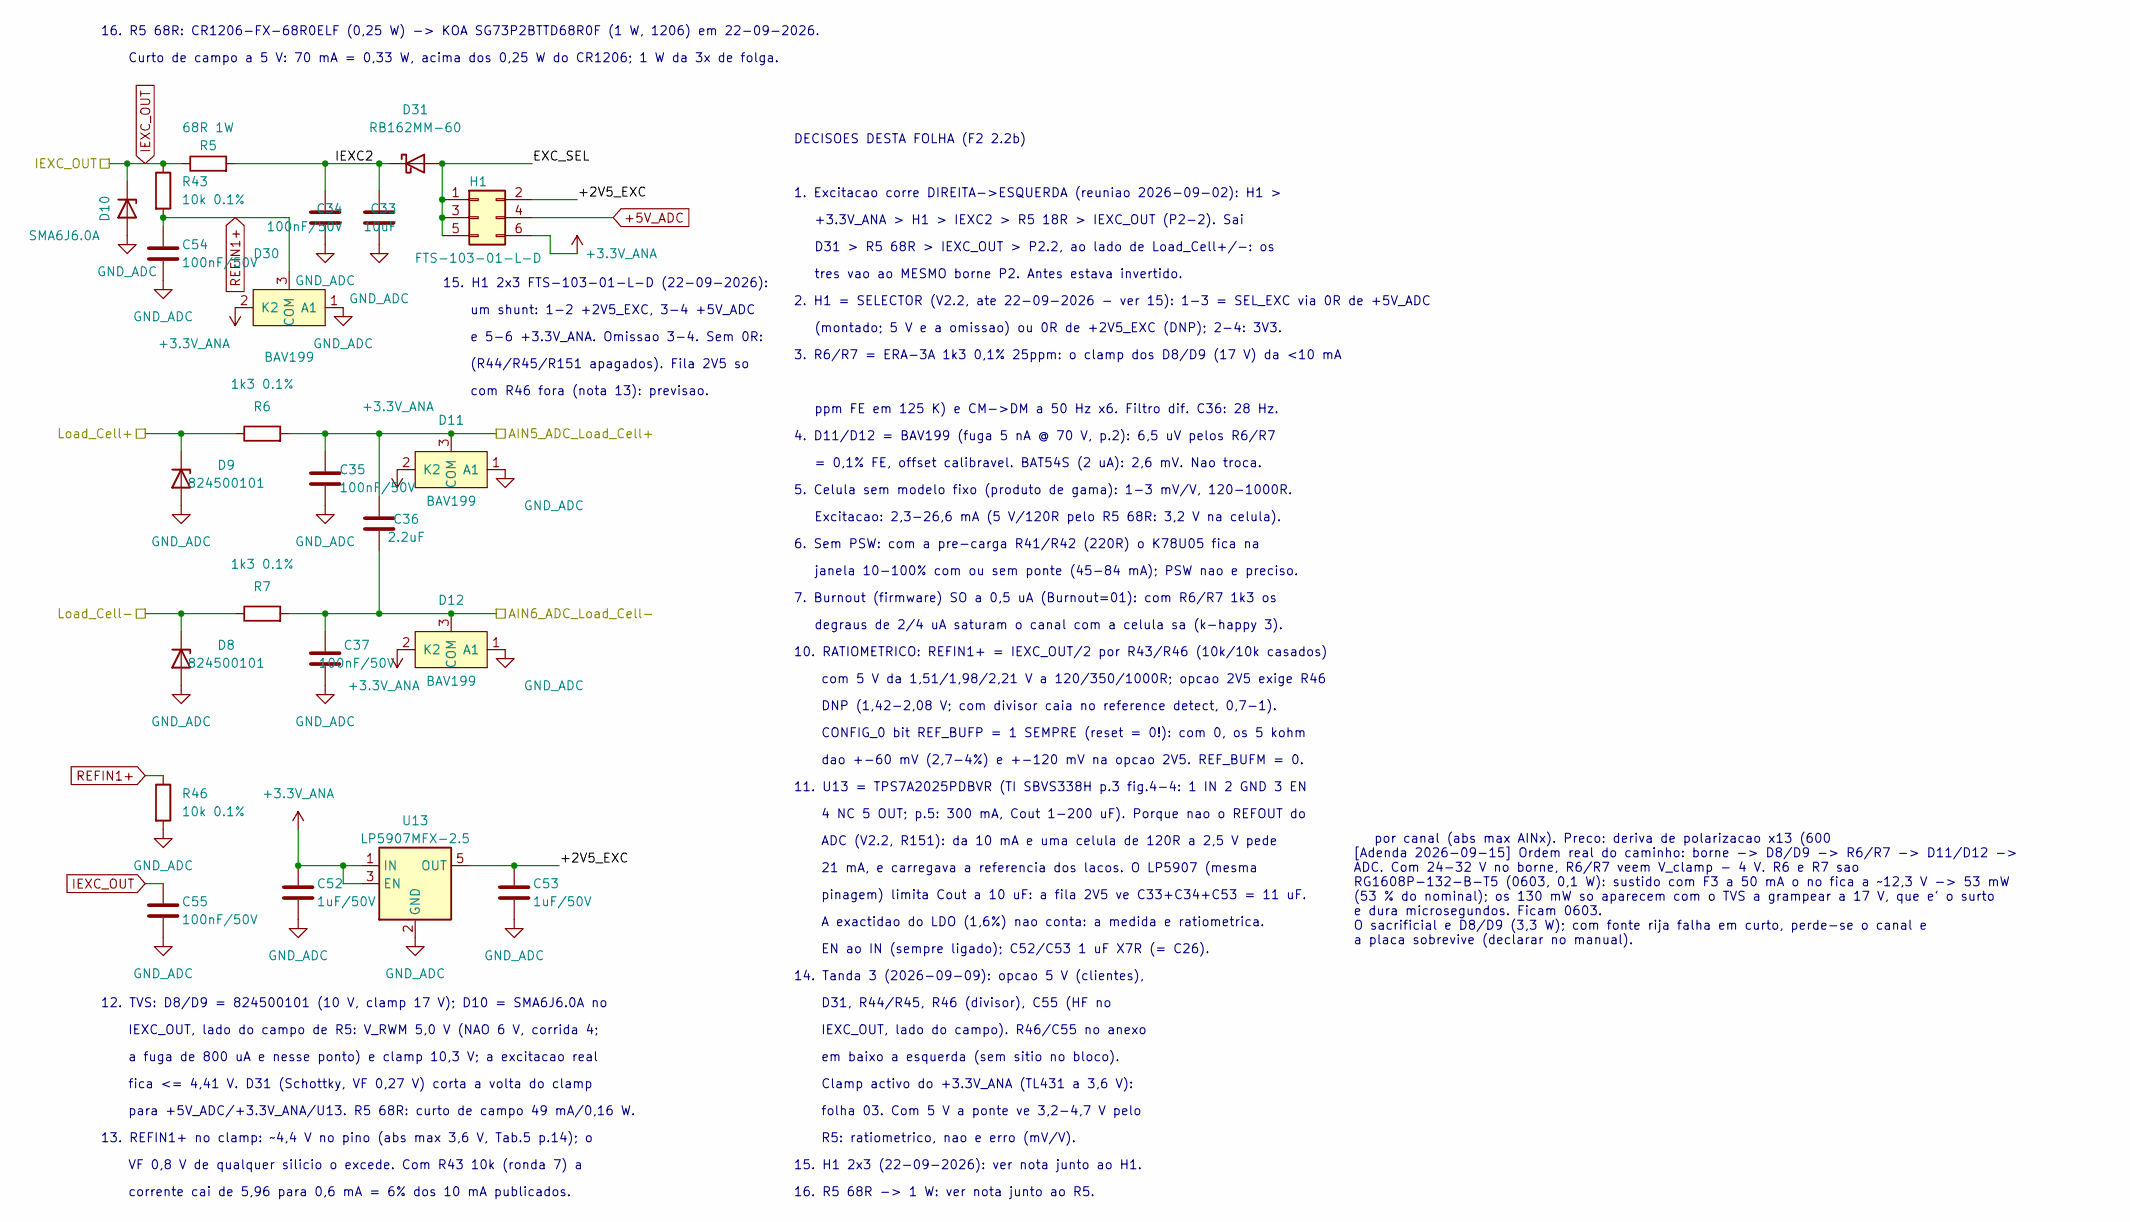
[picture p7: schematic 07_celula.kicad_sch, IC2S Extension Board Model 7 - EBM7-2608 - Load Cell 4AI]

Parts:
C33: 10uF; 0603C; MPN 0603YD106KAT2A
C34, C35, C37, C54, C55: 100nF/50V; 0603C; MPN C1608X7R1H104K080AA
C36: 2.2uF; 0603C; MPN C1608X5R1E225K080AB
C52, C53: 1uF/50V; 0603C; MPN C1608X7R1H105K080AB
D8, D9: 824500101; DO-214; MPN 824500101
D10: SMA6J6.0A; DO-214; MPN SMA6J6.0A
D11, D12, D30: BAV199; SOT23-3; MPN BAV199LT1G
D31: RB162MM-60; SOD-123F; MPN RB162MM-60TR
H1: FTS-103-01-L-D; HDR2X3_1.27mm-Without_number; MPN FTS-103-01-L-D
R5: 68R 1W; 1206R; MPN SG73P2BTTD68R0F
R6, R7: 1k3 0.1%; 0603R; MPN RG1608P-132-B-T5
R43, R46: 10k 0.1%; 0603R; MPN RG1608P-103-B-T5
U13: LP5907MFX-2.5; SOT-23-5; MPN LP5907MFX-2.5/NOPB

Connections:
+5V_ADC: H1.4; also elsewhere on the board
/1 Conectores/Load_Cell+: D9.1 (K), R6.1; also elsewhere on the board
/1 Conectores/Load_Cell-: D8.1 (K), R7.1; also elsewhere on the board
/5 ADC/AIN5_ADC_Load_Cell+: C35.1, C36.2, D11.3 (COM), R6.2; also elsewhere on the board
/5 ADC/AIN6_ADC_Load_Cell-: C36.1, C37.2, D12.3 (COM), R7.2; also elsewhere on the board
/7 Celula de carga/+2V5_EXC: C53.1, H1.2, U13.5 (OUT)
/7 Celula de carga/EXC_SEL: D31.2 (A), H1.1, H1.3, H1.5
/7 Celula de carga/IEXC2: C33.2, C34.2, D31.1 (K), R5.2
IEXC_OUT: C55.1, D10.1 (K), R5.1, R43.1; also elsewhere on the board
REFIN1+: C54.1, D30.3 (COM), R43.2, R46.1; also elsewhere on the board

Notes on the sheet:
ADC (V2.2, R151): da 10 mA e uma celula de 120R a 2,5 V pede
14. Tanda 3 (2026-09-09): opcao 5 V (clientes),
folha 03. Com 5 V a ponte ve 3,2-4,7 V pelo
12. TVS: D8/D9 = 824500101 (10 V, clamp 17 V); D10 = SMA6J6.0A no
IEXC_OUT, lado do campo). R46/C55 no anexo
fica <= 4,41 V. D31 (Schottky, VF 0,27 V) corta a volta do clamp
dao +-60 mV (2,7-4%) e +-120 mV na opcao 2V5. REF_BUFM = 0.
a fuga de 800 uA e nesse ponto) e clamp 10,3 V; a excitacao real
Clamp activo do +3.3V_ANA (TL431 a 3,6 V):
EN ao IN (sempre ligado); C52/C53 1 uF X7R (= C26).
13. REFIN1+ no clamp: ~4,4 V no pino (abs max 3,6 V, Tab.5 p.14); o
com 5 V da 1,51/1,98/2,21 V a 120/350/1000R; opcao 2V5 exige R46
corrente cai de 5,96 para 0,6 mA = 6% dos 10 mA publicados.
5. Celula sem modelo fixo (produto de gama): 1-3 mV/V, 120-1000R.
4. D11/D12 = BAV199 (fuga 5 nA @ 70 V, p.2): 6,5 uV pelos R6/R7
7. Burnout (firmware) SO a 0,5 uA (Burnout=01): com R6/R7 1k3 os
VF 0,8 V de qualquer silicio o excede. Com R43 10k (ronda 7) a
A exactidao do LDO (1,6%) nao conta: a medida e ratiometrica.
4 NC 5 OUT; p.5: 300 mA, Cout 1-200 uF). Porque nao o REFOUT do
3. R6/R7 = ERA-3A 1k3 0,1% 25ppm: o clamp dos D8/D9 (17 V) da <10 mA
em baixo a esquerda (sem sitio no bloco).
2. H1 = SELECTOR (V2.2, ate 22-09-2026 - ver 15): 1-3 = SEL_EXC via 0R de +5V_ADC
degraus de 2/4 uA saturam o canal com a celula sa (k-happy 3).
CONFIG_0 bit REF_BUFP = 1 SEMPRE (reset = 0!): com 0, os 5 kohm
Excitacao: 2,3-26,6 mA (5 V/120R pelo R5 68R: 3,2 V na celula).
para +5V_ADC/+3.3V_ANA/U13. R5 68R: curto de campo 49 mA/0,16 W.
IEXC_OUT, lado do campo de R5: V_RWM 5,0 V (NAO 6 V, corrida 4;
R5: ratiometrico, nao e erro (mV/V).
1. Excitacao corre DIREITA->ESQUERDA (reuniao 2026-09-02): H1 >
D31 > R5 68R > IEXC_OUT > P2.2, ao lado de Load_Cell+/-: os
DNP (1,42-2,08 V; com divisor caia no reference detect, 0,7-1).
+3.3V_ANA > H1 > IEXC2 > R5 18R > IEXC_OUT (P2-2). Sai
ppm FE em 125 K) e CM->DM a 50 Hz x6. Filtro dif. C36: 28 Hz.
por canal (abs max AINx). Preco: deriva de polarizacao x13 (600 [Adenda 2026-09-15] Ordem real do caminho: borne -> D8/D9 -> R6/R7 -> D11/D12 -> ADC. Com 24-32 V no borne, R6/R7 veem V_clamp - 4 V. R6 e R7 sao RG1608P-132-B-T5 (0603, 0,1 W): sustido com F3 a 50 mA o no fica a ~12,3 V -> 53 mW (53 %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
6. Sem PSW: com a pre-carga R41/R42 (220R) o K78U05 fica na
janela 10-100% com ou sem ponte (45-84 mA); PSW nao e preciso.
= 0,1% FE, offset calibravel. BAT54S (2 uA): 2,6 mV. Nao troca.
10. RATIOMETRICO: REFIN1+ = IEXC_OUT/2 por R43/R46 (10k/10k casados)
21 mA, e carregava a referencia dos lacos. O LP5907 (mesma
11. U13 = TPS7A2025PDBVR (TI SBVS338H p.3 fig.4-4: 1 IN 2 GND 3 EN

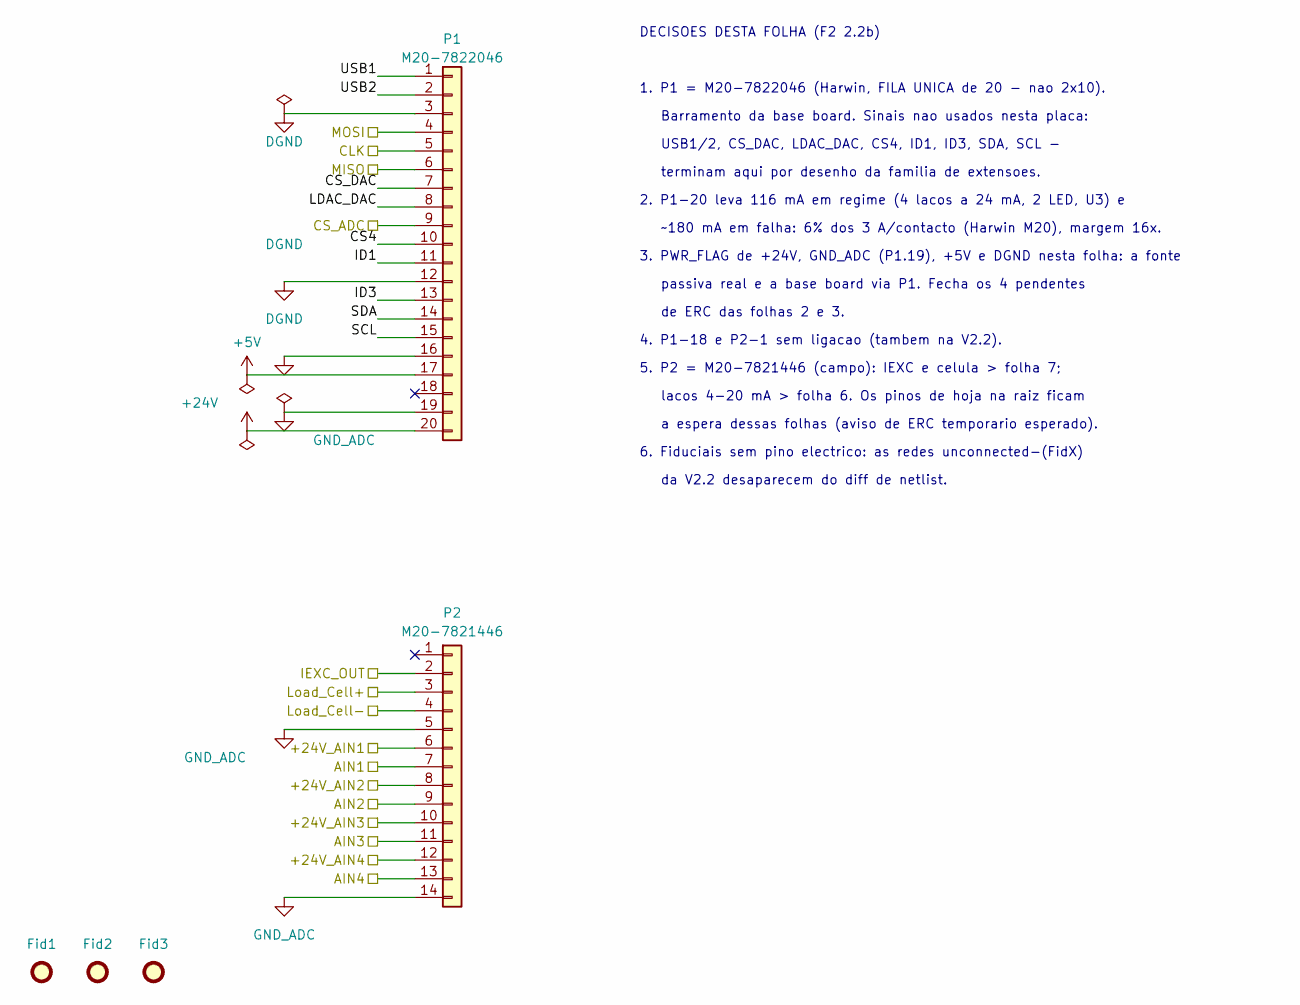
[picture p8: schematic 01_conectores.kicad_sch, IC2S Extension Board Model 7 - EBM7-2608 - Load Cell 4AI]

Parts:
Fid1, Fid2, Fid3: Fiducial; Fiducial_Point_Top-Bot
P1: M20-7822046; HDR1X20_FEMALE; MPN M20-7822046
P2: M20-7821446; HDR1X14_FEMALE; MPN M20-7821446

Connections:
+5V: P1.17; also elsewhere on the board
+24V: P1.20; also elsewhere on the board
/1 Conectores/+24V_AIN1: P2.6; also elsewhere on the board
/1 Conectores/+24V_AIN2: P2.8; also elsewhere on the board
/1 Conectores/+24V_AIN3: P2.10; also elsewhere on the board
/1 Conectores/+24V_AIN4: P2.12; also elsewhere on the board
/1 Conectores/AIN1: P2.7; also elsewhere on the board
/1 Conectores/AIN2: P2.9; also elsewhere on the board
/1 Conectores/AIN3: P2.11; also elsewhere on the board
/1 Conectores/AIN4: P2.13; also elsewhere on the board
/1 Conectores/CS4: P1.10
/1 Conectores/CS_DAC: P1.7
/1 Conectores/ID1: P1.11
/1 Conectores/ID3: P1.13
/1 Conectores/LDAC_DAC: P1.8
/1 Conectores/Load_Cell+: P2.3; also elsewhere on the board
/1 Conectores/Load_Cell-: P2.4; also elsewhere on the board
/1 Conectores/SCL: P1.15
/1 Conectores/SDA: P1.14
/1 Conectores/USB1: P1.1
/1 Conectores/USB2: P1.2
/CLK: P1.5; also elsewhere on the board
/CS_ADC: P1.9; also elsewhere on the board
/MISO: P1.6; also elsewhere on the board
/MOSI: P1.4; also elsewhere on the board
DGND: P1.3, P1.12, P1.16; also elsewhere on the board
IEXC_OUT: P2.2; also elsewhere on the board

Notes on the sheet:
de ERC das folhas 2 e 3.
Barramento da base board. Sinais nao usados nesta placa:
4. P1-18 e P2-1 sem ligacao (tambem na V2.2).
lacos 4-20 mA > folha 6. Os pinos de hoja na raiz ficam
~180 mA em falha: 6% dos 3 A/contacto (Harwin M20), margem 16x.
USB1/2, CS_DAC, LDAC_DAC, CS4, ID1, ID3, SDA, SCL -
6. Fiduciais sem pino electrico: as redes unconnected-(FidX)
5. P2 = M20-7821446 (campo): IEXC e celula > folha 7;
1. P1 = M20-7822046 (Harwin, FILA UNICA de 20 - nao 2x10).
2. P1-20 leva 116 mA em regime (4 lacos a 24 mA, 2 LED, U3) e
da V2.2 desaparecem do diff de netlist.
DECISOES DESTA FOLHA (F2 2.2b)
passiva real e a base board via P1. Fecha os 4 pendentes
3. PWR_FLAG de +24V, GND_ADC (P1.19), +5V e DGND nesta folha: a fonte
terminam aqui por desenho da familia de extensoes.
a espera dessas folhas (aviso de ERC temporario esperado).

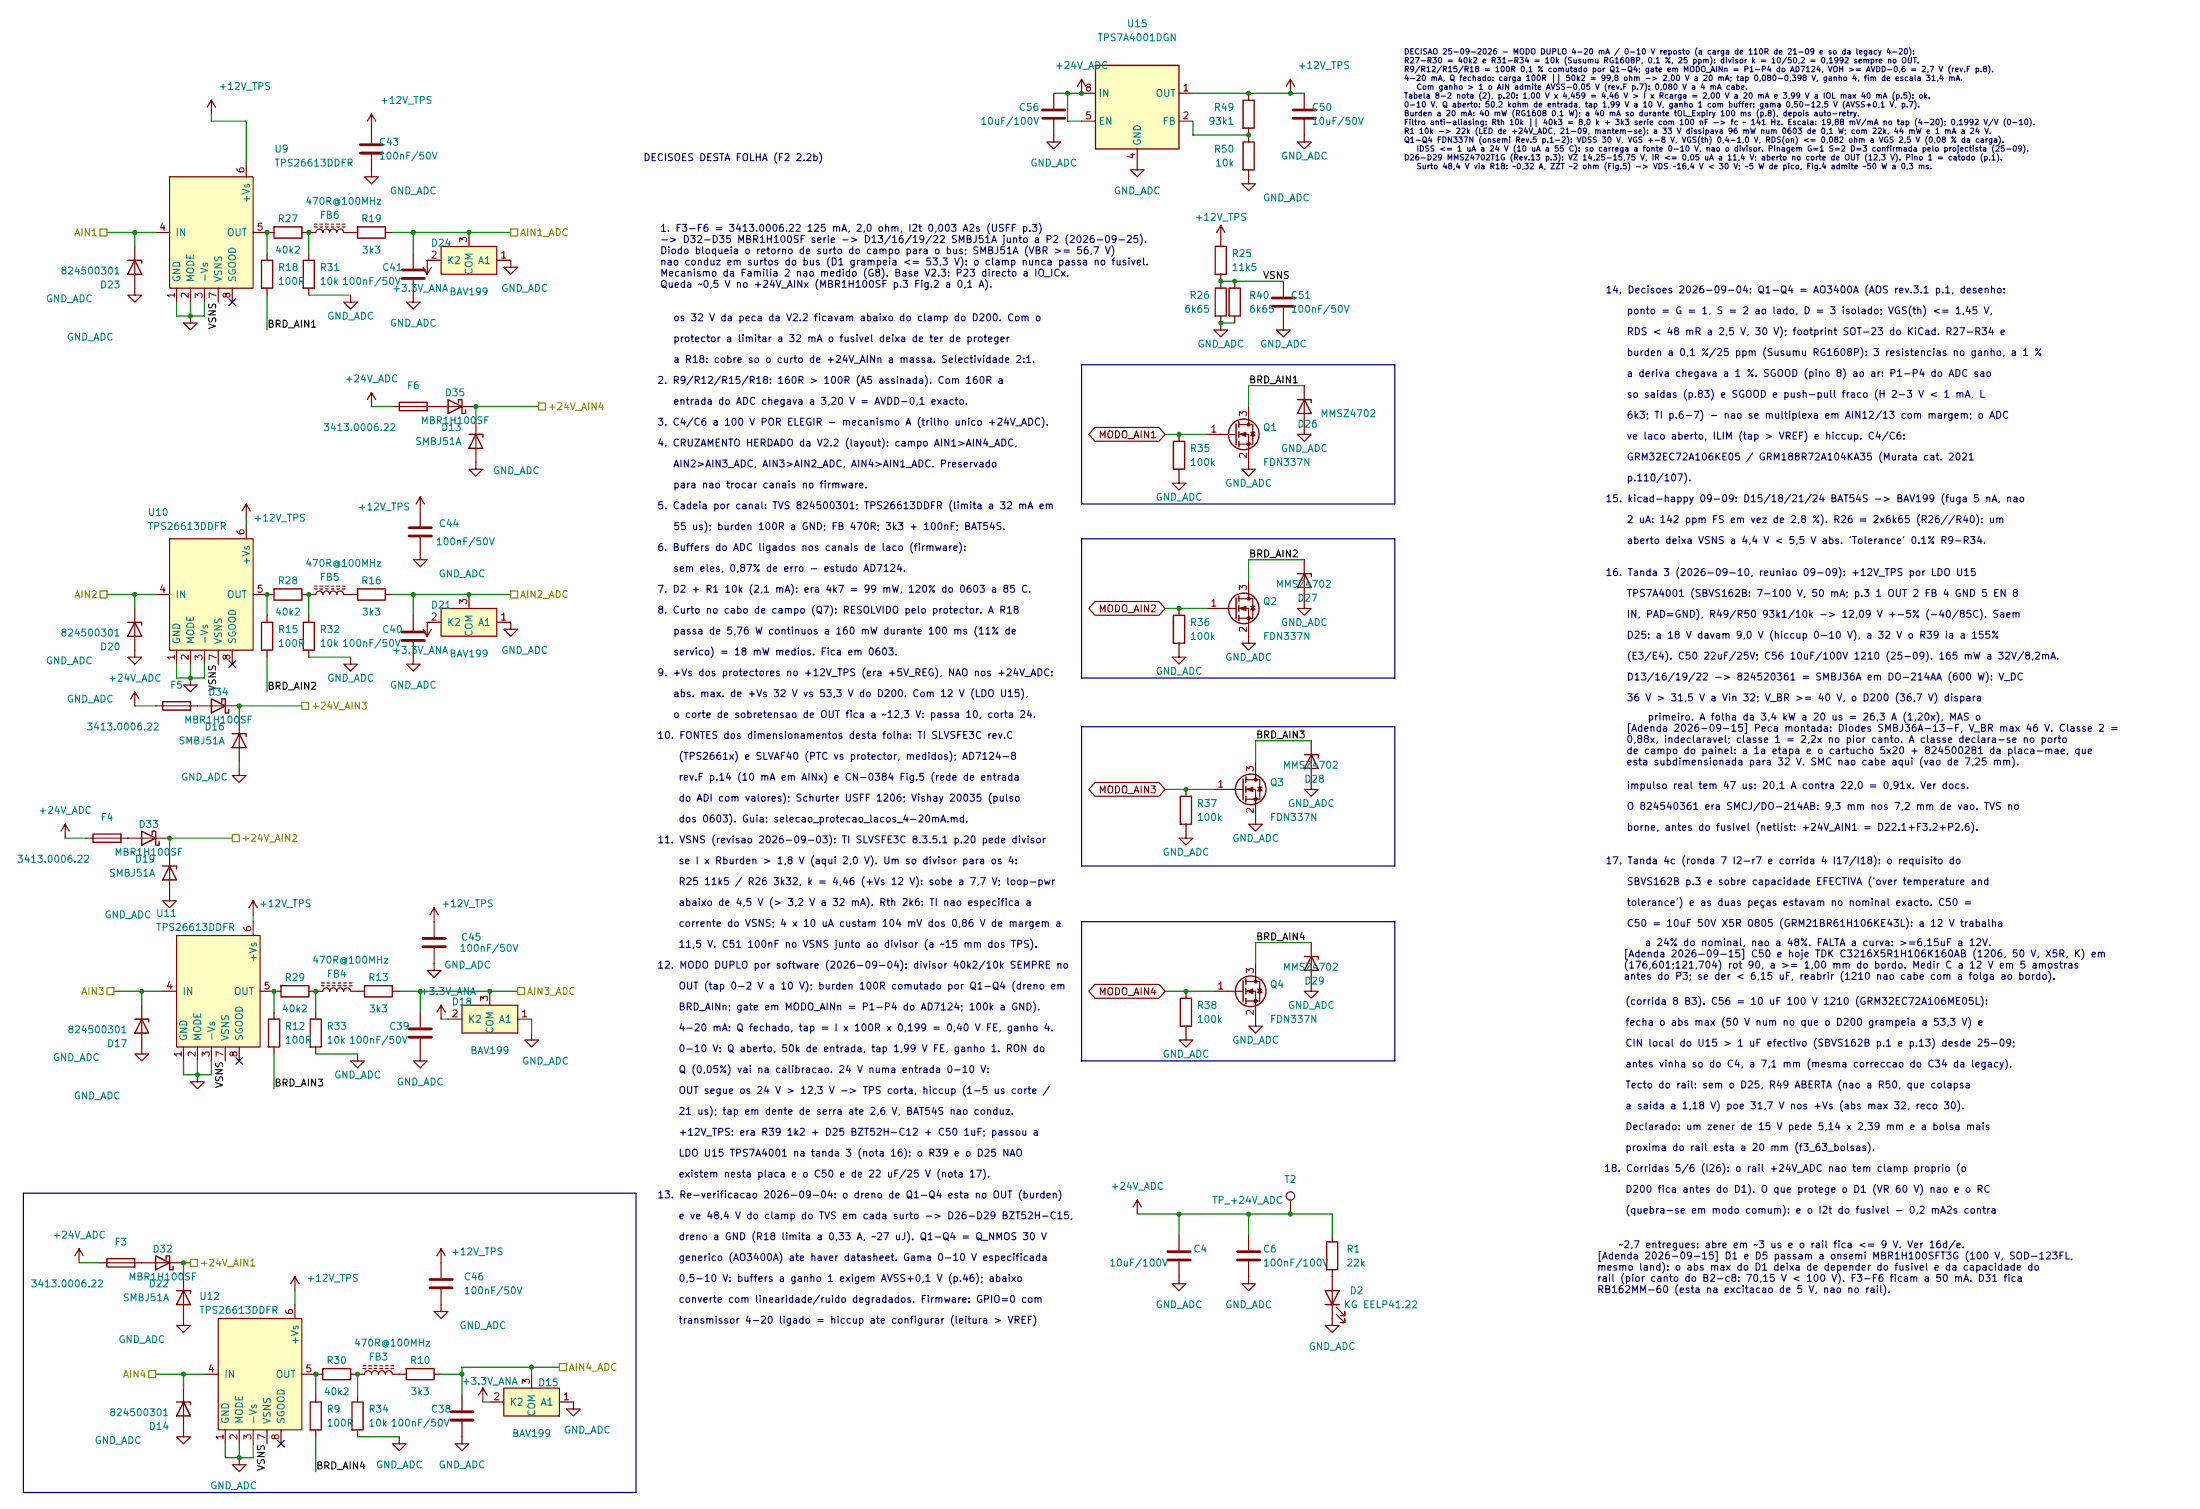
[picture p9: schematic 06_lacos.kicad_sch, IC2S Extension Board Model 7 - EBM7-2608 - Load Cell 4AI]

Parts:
C4, C56: 10uF/100V; C_1210_3225Metric; MPN GRM32EC72A106ME05L
C6: 100nF/100V; 0603C; MPN GRM188R72A104KA35D
C38, C39, C40, C41, C43, C44, C45, C46, C51: 100nF/50V; 0603C; MPN C1608X7R1H104K080AA
C50: 10uF/50V; C_1206_3216Metric; MPN C3216X5R1H106K160AB
D2: KG EELP41.22; 0603LED; MPN KG EELP41.22-PHRH-35-A8J8-20-R18
D13, D16, D19, D22: SMBJ51A; DO-214AA; MPN SMBJ51A-13-F
D14, D17, D20, D23: 824500301; DO-214; MPN 824500301
D15, D18, D21, D24: BAV199; SOT23-3; MPN BAV199LT1G
D26, D27, D28, D29: MMSZ4702; SOD123; MPN MMSZ4702T1G
D32, D33, D34, D35: MBR1H100SF; SOD123; MPN MBR1H100SFT3G
F3, F4, F5, F6: 3413.0006.22; 1206F; MPN 3413.0006.22
FB3, FB4, FB5, FB6: 470R@100MHz; 0603FB; MPN BLM18PG471SN1D
Q1, Q2, Q3, Q4: FDN337N; SOT-23; MPN FDN337N
R1: 22k; 0603R; MPN ERJ-3EKF2202V
R9, R12, R15, R18: 100R; 0603R; Tolerance 0.1%; MPN RG1608P-101-B-T5
R10, R13, R16, R19: 3k3; 0603R; MPN RC0603FR-073K3L
R25: 11k5; 0603R; MPN RC0603FR-0711K5L
R26, R40: 6k65; 0603R; MPN RC0603FR-076K65L
R27, R28, R29, R30: 40k2; 0603R; Tolerance 0.1%; MPN RG1608P-4022-B-T5
R31, R32, R33, R34: 10k; 0603R; Tolerance 0.1%; MPN RG1608P-103-B-T5
R35, R36, R37, R38: 100k; 0603R; MPN RC0603FR-07100KL
R49: 93k1; 0603R; MPN RMCF0603FT93K1
R50: 10k; 0603R; MPN RC0603FR-0710KL
T2: TP_+24V_ADC; TestPad_Via
U9, U10, U11, U12: TPS26613DDFR; SOT-23-8; MPN TPS26613DDFR
U15: TPS7A4001DGN; HVSSOP-8-1EP; MPN TPS7A4001DGNR

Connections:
+12V_TPS: C43.1, C44.1, C45.1, C46.1, C50.1, R25.1, R49.1, U9.6 (+Vs), U10.6 (+Vs), U11.6 (+Vs), U12.6 (+Vs), U15.1 (OUT)
+24V_ADC: C4.1, C6.1, C56.1, F3.1, F4.1, F5.1, F6.1, R1.1, T2.1 (1_1), U15.5 (EN), U15.8 (IN); also elsewhere on the board
/1 Conectores/+24V_AIN1: D22.1 (K), D32.1 (K); also elsewhere on the board
/1 Conectores/+24V_AIN2: D19.1 (K), D33.1 (K); also elsewhere on the board
/1 Conectores/+24V_AIN3: D16.1 (K), D34.1 (K); also elsewhere on the board
/1 Conectores/+24V_AIN4: D13.1 (K), D35.1 (K); also elsewhere on the board
/1 Conectores/AIN1: D23.1 (K), U9.4 (IN); also elsewhere on the board
/1 Conectores/AIN2: D20.1 (K), U10.4 (IN); also elsewhere on the board
/1 Conectores/AIN3: D17.1 (K), U11.4 (IN); also elsewhere on the board
/1 Conectores/AIN4: D14.1 (K), U12.4 (IN); also elsewhere on the board
/5 ADC/AIN1_ADC: C41.2, D24.3 (COM), R19.1; also elsewhere on the board
/5 ADC/AIN2_ADC: C40.2, D21.3 (COM), R16.1; also elsewhere on the board
/5 ADC/AIN3_ADC: C39.2, D18.3 (COM), R13.1; also elsewhere on the board
/5 ADC/AIN4_ADC: C38.2, D15.3 (COM), R10.1; also elsewhere on the board
/6 Lacos 4-20mA/BRD_AIN1: D26.1 (K), Q1.3 (D), R18.2
/6 Lacos 4-20mA/BRD_AIN2: D27.1 (K), Q2.3 (D), R15.2
/6 Lacos 4-20mA/BRD_AIN3: D28.1 (K), Q3.3 (D), R12.2
/6 Lacos 4-20mA/BRD_AIN4: D29.1 (K), Q4.3 (D), R9.2
/6 Lacos 4-20mA/VSNS: C51.1, R25.2, R26.1, R40.1, U9.7 (VSNS), U10.7 (VSNS), U11.7 (VSNS), U12.7 (VSNS)
MODO_AIN1: Q1.1 (G), R35.1; also elsewhere on the board
MODO_AIN2: Q2.1 (G), R36.1; also elsewhere on the board
MODO_AIN3: Q3.1 (G), R37.1; also elsewhere on the board
MODO_AIN4: Q4.1 (G), R38.1; also elsewhere on the board
unnamed: D2.2 (A), R1.2
unnamed: D32.2 (A), F3.2
unnamed: D33.2 (A), F4.2
unnamed: D34.2 (A), F5.2
unnamed: D35.2 (A), F6.2
unnamed: FB3.1, R30.1, R34.1
unnamed: FB3.2, R10.2
unnamed: FB4.1, R29.1, R33.1
unnamed: FB4.2, R13.2
unnamed: FB5.1, R28.1, R32.1
unnamed: FB5.2, R16.2
unnamed: FB6.1, R27.1, R31.1
unnamed: FB6.2, R19.2
unnamed: R18.1, R27.2, U9.5 (OUT)
unnamed: R15.1, R28.2, U10.5 (OUT)
unnamed: R12.1, R29.2, U11.5 (OUT)
unnamed: R9.1, R30.2, U12.5 (OUT)
unnamed: R49.2, R50.1, U15.2 (FB)

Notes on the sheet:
CIN local do U15 > 1 uF efectivo (SBVS162B p.1 e p.13) desde 25-09;
p.110/107).
BRD_AINn; gate em MODO_AINn = P1-P4 do AD7124; 100k a GND).
9. +Vs dos protectores no +12V_TPS (era +5V_REG), NAO nos +24V_ADC:
18. Corridas 5/6 (I26): o rail +24V_ADC nao tem clamp proprio (o
(quebra-se em modo comum): e o I2t do fusivel - 0,2 mA2s contra
o corte de sobretensao de OUT fica a ~12,3 V: passa 10, corta 24.
55 us); burden 100R a GND; FB 470R; 3k3 + 100nF; BAT54S.
Tecto do rail: sem o D25, R49 ABERTA (nao a R50, que colapsa
~2,7 entregues: abre em ~3 us e o rail fica <= 9 V. Ver 16d/e. [Adenda 2026-09-15] D1 e D5 passam a onsemi MBR1H100SFT3G (100 V, SOD-123FL, mesmo land): o abs max do D1 deixa de depender do fusivel e da capacidade do rail (pior canto do B2-c8: 70,15 V < 100 V). F3-F6 ficam a 50 mA. D31 fica RB162MM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
17. Tanda 4c (ronda 7 I2-r7 e corrida 4 I17/I18): o requisito do
ponto = G = 1, S = 2 ao lado, D = 3 isolado; VGS(th) <= 1,45 V,
D200 fica antes do D1). O que protege o D1 (VR 60 V) nao e o RC
(E3/E4). C50 22uF/25V; C56 10uF/100V 1210 (25-09). 165 mW a 32V/8,2mA.
4-20 mA: Q fechado, tap = I x 100R x 0,199 = 0,40 V FE, ganho 4.
rev.F p.14 (10 mA em AINx) e CN-0384 Fig.5 (rede de entrada
15. kicad-happy 09-09: D15/18/21/24 BAT54S -> BAV199 (fuga 5 nA, nao
AIN2>AIN3_ADC, AIN3>AIN2_ADC, AIN4>AIN1_ADC. Preservado
dreno a GND (R18 limita a 0,33 A, ~27 uJ). Q1-Q4 = Q_NMOS 30 V
passa de 5,76 W continuos a 160 mW durante 100 ms (11% de
14. Decisoes 2026-09-04: Q1-Q4 = AO3400A (AOS rev.3.1 p.1, desenho:
DECISOES DESTA FOLHA (F2 2.2b)
7. D2 + R1 10k (2,1 mA): era 4k7 = 99 mW, 120% do 0603 a 85 C.
abaixo de 4,5 V (> 3,2 V a 32 mA). Rth 2k6: TI nao especifica a
4. CRUZAMENTO HERDADO da V2.2 (layout): campo AIN1>AIN4_ADC,
(corrida 8 B3). C56 = 10 uF 100 V 1210 (GRM32EC72A106ME05L):
protector a limitar a 32 mA o fusivel deixa de ter de proteger
burden a 0,1 %/25 ppm (Susumu RG1608P): 3 resistencias no ganho, a 1 %
antes vinha so do C4, a 7,1 mm (mesma correccao do C34 da legacy).
borne, antes do fusivel (netlist: +24V_AIN1 = D22.1+F3.2+P2.6).
(TPS2661x) e SLVAF40 (PTC vs protector, medidos); AD7124-8
R25 11k5 / R26 3k32, k = 4,46 (+Vs 12 V): sobe a 7,7 V; loop-pwr
OUT segue os 24 V > 12,3 V -> TPS corta, hiccup (1-5 us corte /
5. Cadeia por canal: TVS 824500301; TPS26613DDFR (limita a 32 mA em
generico (AO3400A) ate haver datasheet. Gama 0-10 V especificada
10. FONTES dos dimensionamentos desta folha: TI SLVSFE3C rev.C
servico) = 18 mW medios. Fica em 0603.
1. F3-F6 = 3413.0006.22 125 mA, 2,0 ohm, I2t 0,003 A2s (USFF p.3) -> D32-D35 MBR1H100SF serie -> D13/16/19/22 SMBJ51A junto a P2 (2026-09-25). Diodo bloqueia o retorno de surto do campo para o bus; SMBJ51A (VBR >= 56,7 V) nao conduz em surtos do bus (D1 grampeia <= 53,3 V): o clamp nunca passa no f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
LDO U15 TPS7A4001 na tanda 3 (nota 16): o R39 e o D25 NAO
0-10 V: Q aberto, 50k de entrada, tap 1,99 V FE, ganho 1. RON do

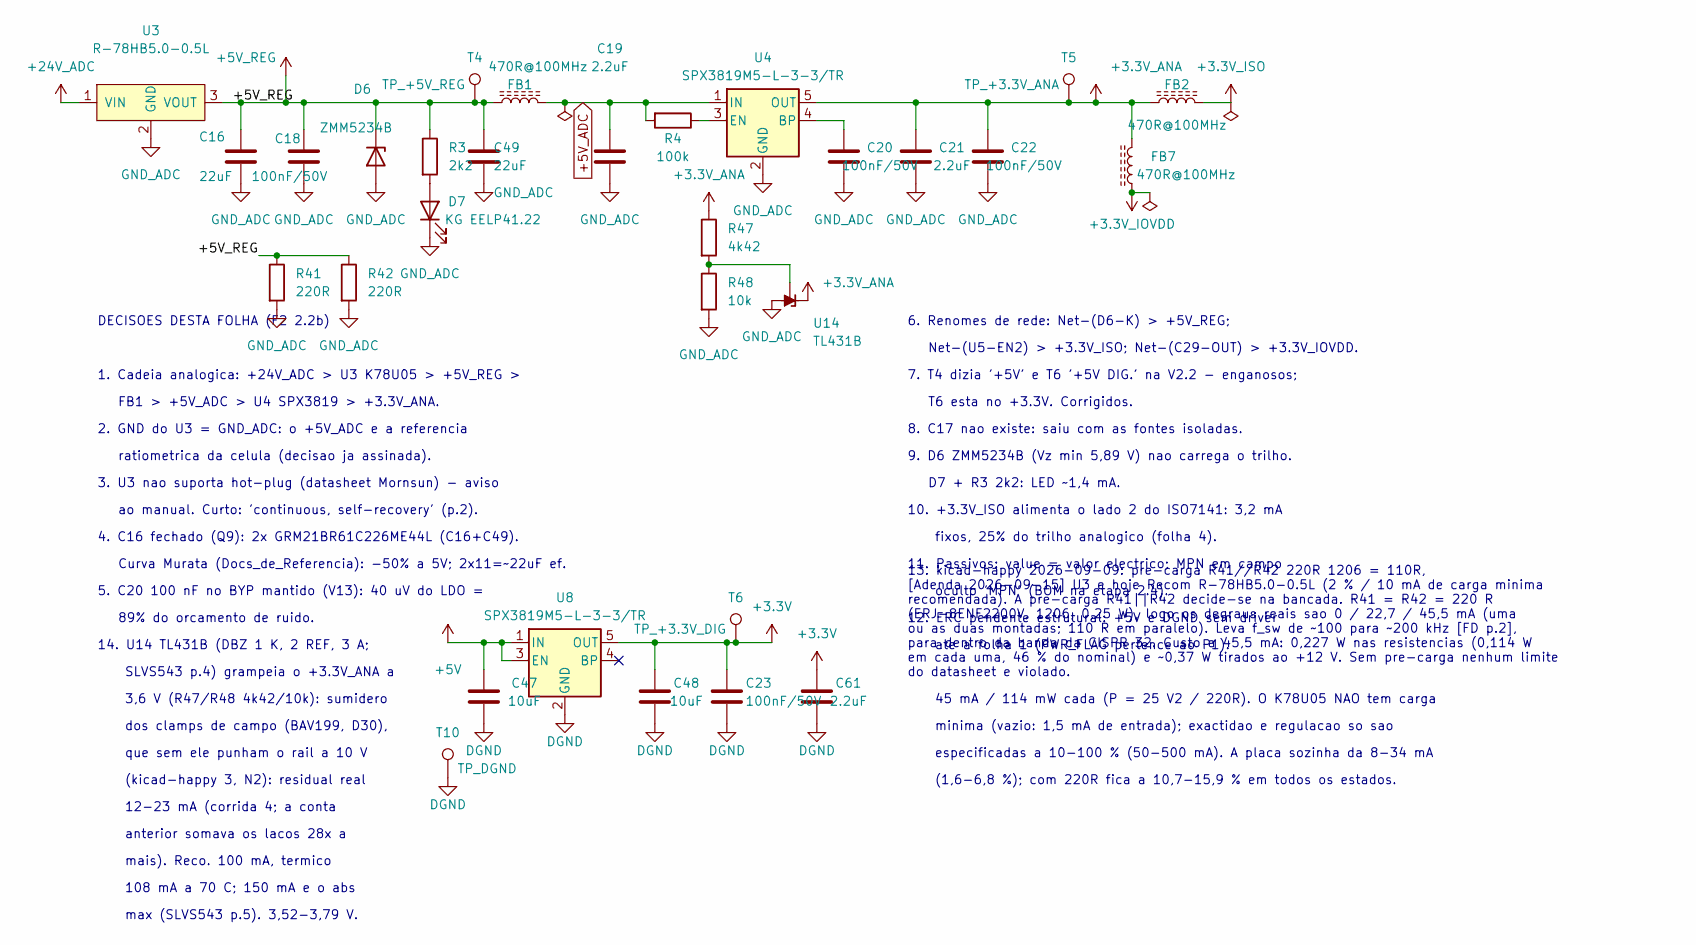
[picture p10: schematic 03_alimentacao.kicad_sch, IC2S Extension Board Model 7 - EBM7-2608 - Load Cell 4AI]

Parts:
C16, C49: 22uF; C_0805_2012Metric; MPN CL21A226KOQNNNG
C18, C20, C22, C23: 100nF/50V; 0603C; MPN C1608X7R1H104K080AA
C19, C21, C61: 2.2uF; 0603C; MPN C1608X5R1E225K080AB
C47, C48: 10uF; 0603C; MPN 0603YD106KAT2A
D6: ZMM5234B; SOD-80C; MPN ZMM5234B
D7: KG EELP41.22; 0603LED; MPN KG EELP41.22-PHRH-35-A8J8-20-R18
FB1, FB2, FB7: 470R@100MHz; 0603FB; MPN BLM18PG471SN1D
R3: 2k2; 0603R; MPN RC0603FR-072K2L
R4: 100k; 0603R; MPN CRCW0603100KFKEA
R41, R42: 220R; 1206R; MPN RC1206FR-07220RL
R47: 4k42; 0603R; MPN RMCF0603FT4K42
R48: 10k; 0603R; MPN RC0603FR-0710KL
T4: TP_+5V_REG; TestPad_Via
T5: TP_+3.3V_ANA; TestPad_Via
T6: TP_+3.3V_DIG; TestPad_Via
T10: TP_DGND; TestPad_Via
U3: R-78HB5.0-0.5L; R-78HBxx-0.5L_SIP-3H; MPN R-78HB5.0-0.5L
U4, U8: SPX3819M5-L-3-3/TR; SOT-23-5; MPN SPX3819M5-L-3-3/TR
U14: TL431B; SOT23-3; MPN TL431BQDBZR

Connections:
+3.3V: C23.1, C48.2, C61.2, T6.1 (1_1), U8.5 (OUT); also elsewhere on the board
+3.3V_IOVDD: FB7.1; also elsewhere on the board
+3.3V_ISO: FB2.2; also elsewhere on the board
+5V: C47.2, U8.1 (IN), U8.3 (EN); also elsewhere on the board
+5V_ADC: C19.2, FB1.2, R4.2, U4.1 (IN); also elsewhere on the board
+5V_REG: C16.2, C18.2, C49.2, D6.1 (K), FB1.1, R3.1, R41.1, R42.1, T4.1 (1_1), U3.3 (VOUT)
+24V_ADC: U3.1 (VIN); also elsewhere on the board
DGND: C23.2, C47.1, C48.1, C61.1, T10.1 (1_1), U8.2 (GND); also elsewhere on the board
unnamed: D7.2 (A), R3.2
unnamed: C20.2, U4.4 (BP)
unnamed: R4.1, U4.3 (EN)
unnamed: R47.2, R48.1, U14.2 (REF)

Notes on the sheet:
dos clamps de campo (BAV199, D30),
mais). Reco. 100 mA, termico
ate a folha 1 (PWR_FLAG pertence ao P1).
8. C17 nao existe: saiu com as fontes isoladas.
minima (vazio: 1,5 mA de entrada); exactidao e regulacao so sao
7. T4 dizia '+5V' e T6 '+5V DIG.' na V2.2 - enganosos;
6. Renomes de rede: Net-(D6-K) > +5V_REG;
3. U3 nao suporta hot-plug (datasheet Mornsun) - aviso
3,6 V (R47/R48 4k42/10k): sumidero
ratiometrica da celula (decisao ja assinada).
D7 + R3 2k2: LED ~1,4 mA.
FB1 > +5V_ADC > U4 SPX3819 > +3.3V_ANA.
que sem ele punham o rail a 10 V
4. C16 fechado (Q9): 2x GRM21BR61C226ME44L (C16+C49).
108 mA a 70 C; 150 mA e o abs
14. U14 TL431B (DBZ 1 K, 2 REF, 3 A;
anterior somava os lacos 28x a
Curva Murata (Docs_de_Referencia): -50% a 5V; 2x11=~22uF ef.
10. +3.3V_ISO alimenta o lado 2 do ISO7141: 3,2 mA
T6 esta no +3.3V. Corrigidos.
oculto 'MPN' (BOM na etapa 2.4).
13. kicad-happy 2026-09-09: pre-carga R41//R42 220R 1206 = 110R, [Adenda 2026-09-15] U3 e hoje Recom R-78HB5.0-0.5L (2 % / 10 mA de carga minima recomendada). A pre-carga R41||R42 decide-se na bancada. R41 = R42 = 220 R (ERJ-8ENF2200V, 1206, 0,25 W), logo os degraus reais sao 0 / 22,7 / 45,5 mA (um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
11. Passivos: value = valor electrico; MPN em campo
12. ERC pendente estrutural: +5V e DGND sem driver
2. GND do U3 = GND_ADC: o +5V_ADC e a referencia
(1,6-6,8 %); com 220R fica a 10,7-15,9 % em todos os estados.
fixos, 25% do trilho analogico (folha 4).
5. C20 100 nF no BYP mantido (V13): 40 uV do LDO =
1. Cadeia analogica: +24V_ADC > U3 K78U05 > +5V_REG >
Net-(U5-EN2) > +3.3V_ISO; Net-(C29-OUT) > +3.3V_IOVDD.
DECISOES DESTA FOLHA (F2 2.2b)
SLVS543 p.4) grampeia o +3.3V_ANA a
(kicad-happy 3, N2): residual real
45 mA / 114 mW cada (P = 25 V2 / 220R). O K78U05 NAO tem carga
ao manual. Curto: 'continuous, self-recovery' (p.2).
9. D6 ZMM5234B (Vz min 5,89 V) nao carrega o trilho.
12-23 mA (corrida 4; a conta
especificadas a 10-100 % (50-500 mA). A placa sozinha da 8-34 mA
89% do orcamento de ruido.
max (SLVS543 p.5). 3,52-3,79 V.

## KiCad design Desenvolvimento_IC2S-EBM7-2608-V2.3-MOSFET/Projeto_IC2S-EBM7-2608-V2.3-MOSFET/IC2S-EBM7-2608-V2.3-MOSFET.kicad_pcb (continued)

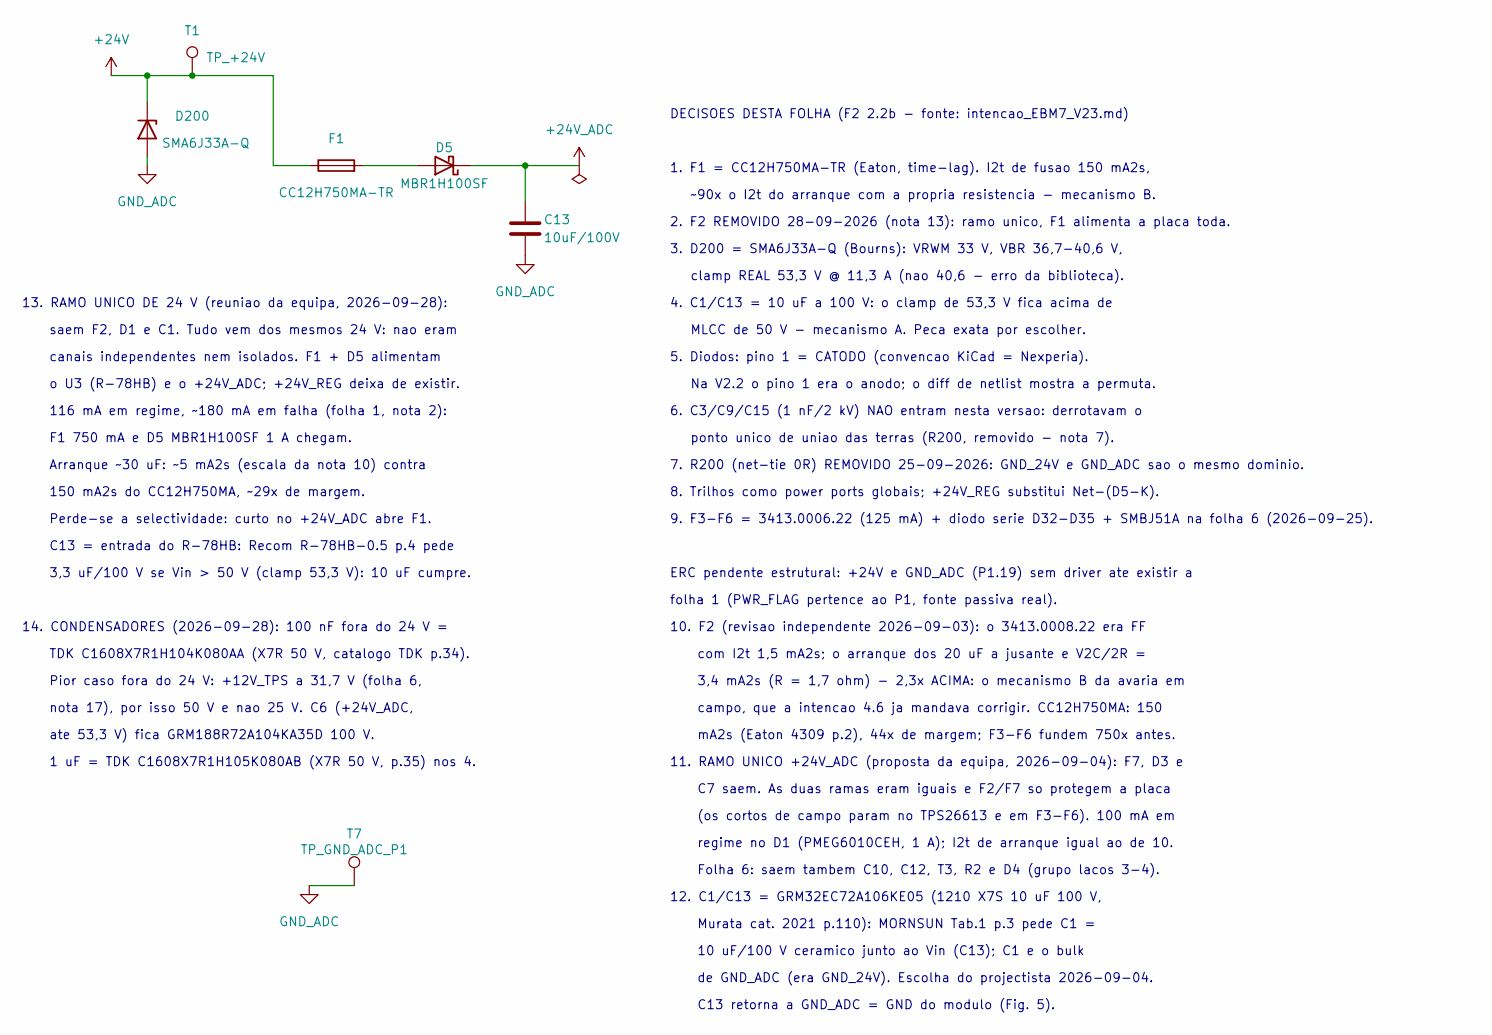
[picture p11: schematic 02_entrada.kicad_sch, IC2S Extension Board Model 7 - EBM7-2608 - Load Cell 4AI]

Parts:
C13: 10uF/100V; C_1210_3225Metric; MPN GRM32EC72A106ME05L
D5: MBR1H100SF; SOD123; MPN MBR1H100SFT3G
D200: SMA6J33A-Q; DO-214; MPN SMA6J33A-Q
F1: CC12H750MA-TR; 1206F; MPN CC12H750MA-TR
T1: TP_+24V; TestPad_Via
T7: TP_GND_ADC_P1; TestPad_Via

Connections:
+24V: D200.1 (K), F1.1, T1.1 (1_1); also elsewhere on the board
+24V_ADC: C13.1, D5.1 (K); also elsewhere on the board
unnamed: D5.2 (A), F1.2

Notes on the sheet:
8. Trilhos como power ports globais; +24V_REG substitui Net-(D5-K).
Murata cat. 2021 p.110): MORNSUN Tab.1 p.3 pede C1 =
5. Diodos: pino 1 = CATODO (convencao KiCad = Nexperia).
Folha 6: saem tambem C10, C12, T3, R2 e D4 (grupo lacos 3-4).
~90x o I2t do arranque com a propria resistencia - mecanismo B.
MLCC de 50 V - mecanismo A. Peca exata por escolher.
12. C1/C13 = GRM32EC72A106KE05 (1210 X7S 10 uF 100 V,
7. R200 (net-tie 0R) REMOVIDO 25-09-2026: GND_24V e GND_ADC sao o mesmo dominio.
com I2t 1,5 mA2s; o arranque dos 20 uF a jusante e V2C/2R =
4. C1/C13 = 10 uF a 100 V: o clamp de 53,3 V fica acima de
6. C3/C9/C15 (1 nF/2 kV) NAO entram nesta versao: derrotavam o
C13 retorna a GND_ADC = GND do modulo (Fig. 5).
de GND_ADC (era GND_24V). Escolha do projectista 2026-09-04.
10. F2 (revisao independente 2026-09-03): o 3413.0008.22 era FF
ponto unico de uniao das terras (R200, removido - nota 7).
9. F3-F6 = 3413.0006.22 (125 mA) + diodo serie D32-D35 + SMBJ51A na folha 6 (2026-09-25).
folha 1 (PWR_FLAG pertence ao P1, fonte passiva real).
campo, que a intencao 4.6 ja mandava corrigir. CC12H750MA: 150
3. D200 = SMA6J33A-Q (Bourns): VRWM 33 V, VBR 36,7-40,6 V,
clamp REAL 53,3 V @ 11,3 A (nao 40,6 - erro da biblioteca).
10 uF/100 V ceramico junto ao Vin (C13); C1 e o bulk
1. F1 = CC12H750MA-TR (Eaton, time-lag). I2t de fusao 150 mA2s,
mA2s (Eaton 4309 p.2), 44x de margem; F3-F6 fundem 750x antes.
ERC pendente estrutural: +24V e GND_ADC (P1.19) sem driver ate existir a
2. F2 REMOVIDO 28-09-2026 (nota 13): ramo unico, F1 alimenta a placa toda.
3,4 mA2s (R = 1,7 ohm) - 2,3x ACIMA: o mecanismo B da avaria em
Na V2.2 o pino 1 era o anodo; o diff de netlist mostra a permuta.
C7 saem. As duas ramas eram iguais e F2/F7 so protegem a placa
11. RAMO UNICO +24V_ADC (proposta da equipa, 2026-09-04): F7, D3 e
(os cortos de campo param no TPS26613 e em F3-F6). 100 mA em
DECISOES DESTA FOLHA (F2 2.2b - fonte: intencao_EBM7_V23.md)
regime no D1 (PMEG6010CEH, 1 A); I2t de arranque igual ao de 10.
13. RAMO UNICO DE 24 V (reuniao da equipa, 2026-09-28):
saem F2, D1 e C1. Tudo vem dos mesmos 24 V: nao eram
canais independentes nem isolados. F1 + D5 alimentam
o U3 (R-78HB) e o +24V_ADC; +24V_REG deixa de existir.
116 mA em regime, ~180 mA em falha (folha 1, nota 2):
F1 750 mA e D5 MBR1H100SF 1 A chegam.
Arranque ~30 uF: ~5 mA2s (escala da nota 10) contra
150 mA2s do CC12H750MA, ~29x de margem.

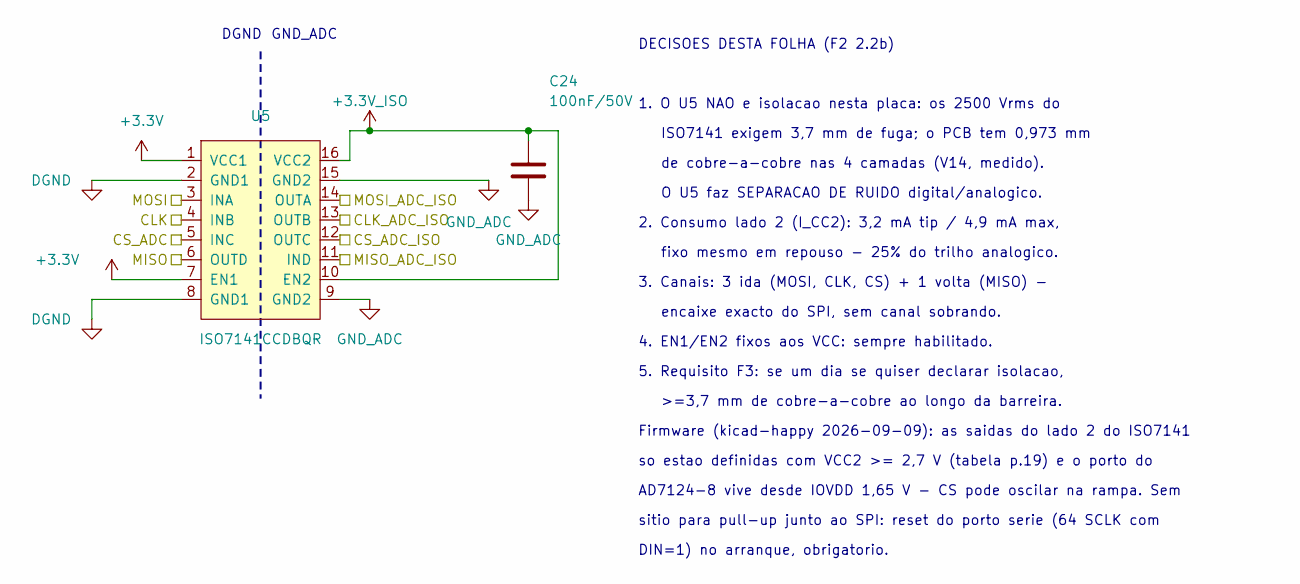
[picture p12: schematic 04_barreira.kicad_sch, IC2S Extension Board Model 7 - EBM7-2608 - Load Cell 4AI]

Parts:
C24: 100nF/50V; 0603C; MPN C1608X7R1H104K080AA
U5: ISO7141CCDBQR; SSOP16-4.9x3.9mm; MPN ISO7141CCDBQR

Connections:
+3.3V: U5.1 (VCC1), U5.7 (EN1); also elsewhere on the board
+3.3V_ISO: C24.1, U5.10 (EN2), U5.16 (VCC2); also elsewhere on the board
/4 Barreira digital/CLK_ADC_ISO: U5.13 (OUTB); also elsewhere on the board
/4 Barreira digital/CS_ADC_ISO: U5.12 (OUTC); also elsewhere on the board
/4 Barreira digital/MISO_ADC_ISO: U5.11 (IND); also elsewhere on the board
/4 Barreira digital/MOSI_ADC_ISO: U5.14 (OUTA); also elsewhere on the board
/CLK: U5.4 (INB); also elsewhere on the board
/CS_ADC: U5.5 (INC); also elsewhere on the board
/MISO: U5.6 (OUTD); also elsewhere on the board
/MOSI: U5.3 (INA); also elsewhere on the board
DGND: U5.2 (GND1), U5.8 (GND1); also elsewhere on the board

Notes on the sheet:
AD7124-8 vive desde IOVDD 1,65 V - CS pode oscilar na rampa. Sem
DECISOES DESTA FOLHA (F2 2.2b)
ISO7141 exigem 3,7 mm de fuga; o PCB tem 0,973 mm
sitio para pull-up junto ao SPI: reset do porto serie (64 SCLK com
encaixe exacto do SPI, sem canal sobrando.
de cobre-a-cobre nas 4 camadas (V14, medido).
5. Requisito F3: se um dia se quiser declarar isolacao,
2. Consumo lado 2 (I_CC2): 3,2 mA tip / 4,9 mA max,
DGND
Firmware (kicad-happy 2026-09-09): as saidas do lado 2 do ISO7141
1. O U5 NAO e isolacao nesta placa: os 2500 Vrms do
O U5 faz SEPARACAO DE RUIDO digital/analogico.
GND_ADC
4. EN1/EN2 fixos aos VCC: sempre habilitado.
3. Canais: 3 ida (MOSI, CLK, CS) + 1 volta (MISO) -
so estao definidas com VCC2 >= 2,7 V (tabela p.19) e o porto do
fixo mesmo em repouso - 25% do trilho analogico.
>=3,7 mm de cobre-a-cobre ao longo da barreira.
DIN=1) no arranque, obrigatorio.

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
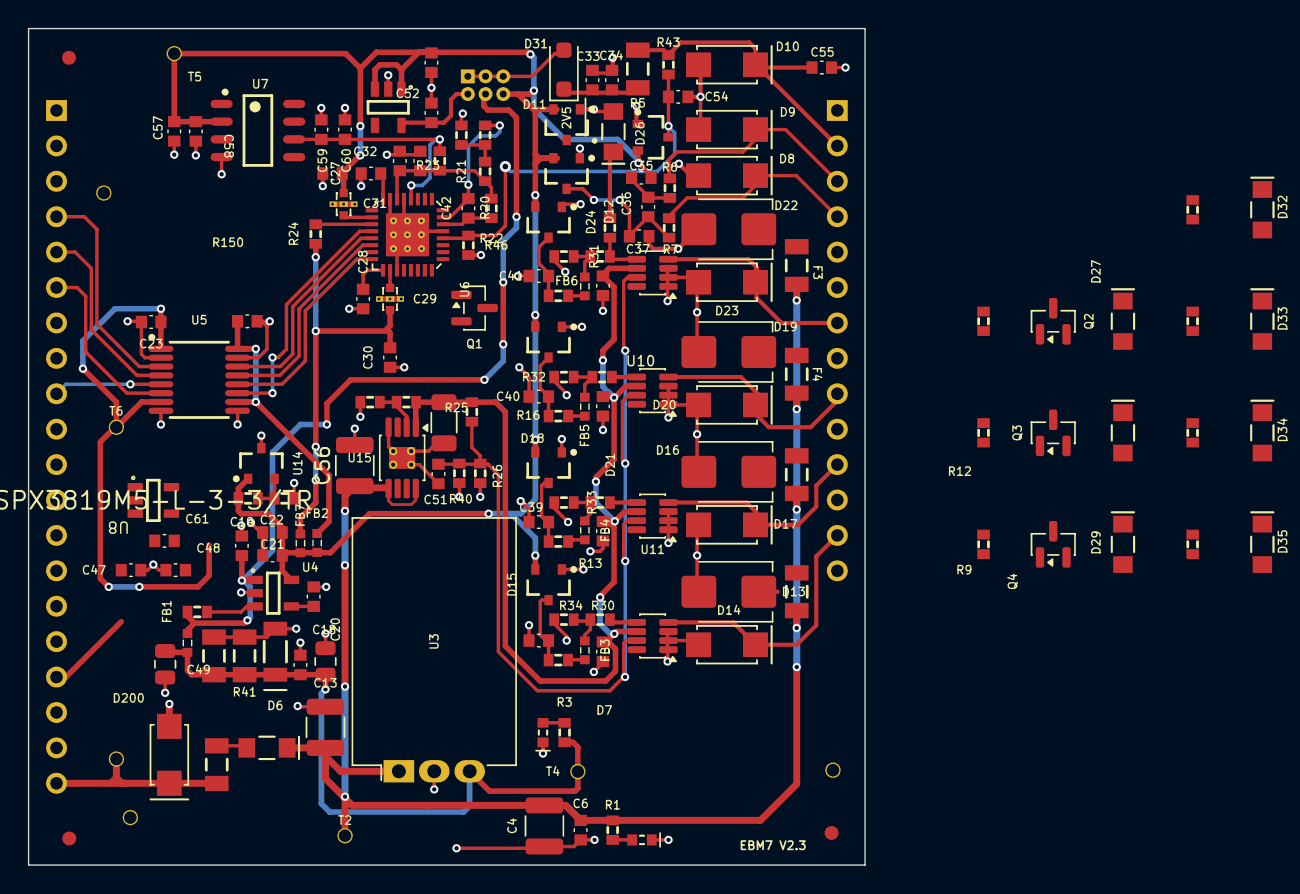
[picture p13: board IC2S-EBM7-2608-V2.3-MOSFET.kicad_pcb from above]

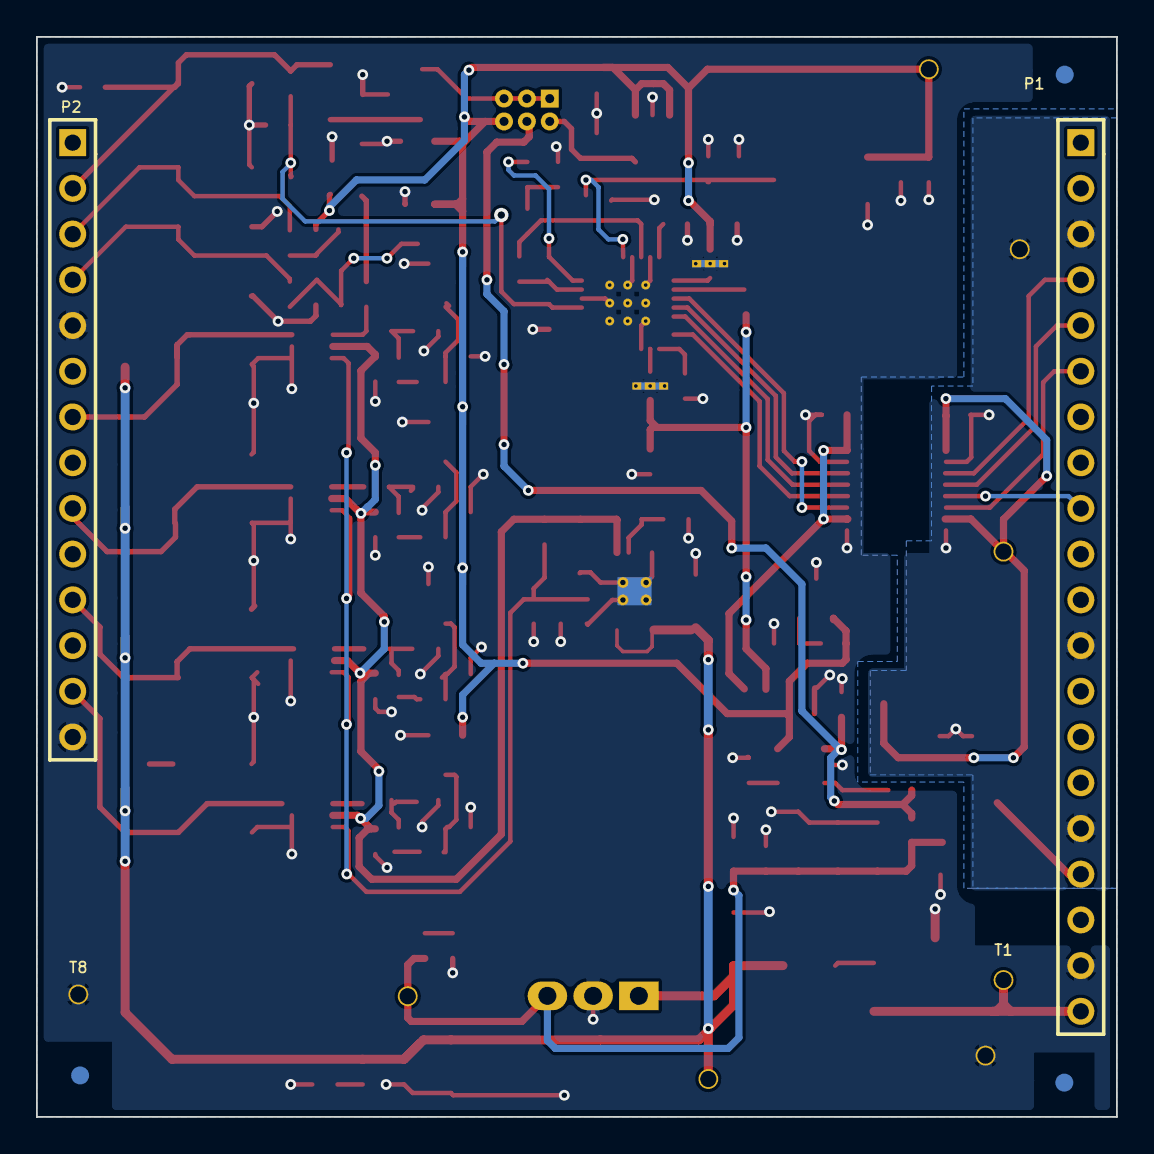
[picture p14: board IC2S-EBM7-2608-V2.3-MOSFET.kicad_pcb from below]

Board: 4 copper layers, 60.0 x 60.0 mm, 166 parts (4 on the bottom side), 83 nets.

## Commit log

2026-09-25 EBM7-2608 V2.3 configuravel 0-10 V / 4-20 mA (MOSFET): projecto KiCad
    Variante com selecao de modo por canal (FDN337N comandado pelas saidas
    P1-P4 do AD7124; divisor 40k2/10k sempre no OUT e burden 100R comutado) e
    protecao completa da alimentacao dos sensores (fusivel -> MBR1H100SF ->
    SMBJ51A no borne). Padrao de pastas dos produtos (Axcel_Sensor), com
    ID = IC2S-EBM7-2608-V2.3-MOSFET; ficheiros KiCad renomeados para
    <ID>.kicad_* (354 referencias internas actualizadas).
    Estado: esquematico fechado (ERC 0 erros, netlist igual ao original:
    168 componentes, 0 pinos com rede diferente). PCB com a colocacao e as
    pistas da variante fixa nas 148 pecas comuns e as 20 pecas proprias por
    colocar: DRC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
    [01_conectores.kicad_sch, 02_entrada.kicad_sch, 03_alimentacao.kicad_sch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]
2026-09-28 Revisao da reuniao 28-09: ramo unico de 24 V, 100 nF a 50 V, um so MPN de 1 uF
    - Saem F2, o diodo e o condensador do ramo +24V_ADC; F1 + diodo alimentam o
    R-78HB e o +24V_ADC. +24V_REG deixa de existir (esquematico, PCB, netclasses).
    - Condensador de entrada do R-78HB conferido contra o datasheet Recom (p.4):
    10 uF/100 V cumpre os 3,3 uF/100 V pedidos com Vin > 50 V. Sem alteracao.
    - 100 nF fora do 24 V -> TDK C1608X7R1H104K080AA (50 V); o do +24V_ADC fica
    GRM188R72A104KA35D (100 V). 1 uF -> TDK C1608X7R1H105K080AB nos quatro.
    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
    [02_entrada.kicad_sch, 03_alimentacao.kicad_sch, 04_barreira.kicad_sch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]
2026-09-28 NTC com simbolo de termistor e explicacao do TL431 do +3.3V_ANA
    - Folha 8: o NTC deixa de usar Device:R e passa a Device:Thermistor_NTC
    (mesmos pinos; netlist e PCB inalterados). Observacao da reuniao de 25-09.
    - Documento porque_TL431_*_no_3V3_ANA.md: o LDO nao absorve corrente, os
    BAV199 despejam os surtos no rail e o TL431 segura-o abaixo do maximo
    absoluto do AD7124; numeros tirados dos datasheets locais.
    Claude-Session: https://claude.ai/code/session_01KPnkiJQKrkjgRqqw9M78ie
    [08_ntc.kicad_sch]
2026-09-28 LDO 3,3 V do lado PLC: U8 MCP1824ST (SOT-223) -> SPX3819M5-L-3-3/TR (SOT-23-5), mesmo MPN do U4
    - Criterio da equipa: menos MPN, mais pecas do mesmo tipo; o MCP1824ST sai.
    - EN a VIN, BYP aberto; estabilidade com ceramico sem garantia no datasheet (provada em campo na V2.2).
    - Esquematico: ERC 0; netlist so muda os pinos do U8. PCB: pegada SOT-23-5 no
    mesmo sitio; faltam rotear 6 ligacoes do U8.
    - Registo: alteracao_LDO_3V3_lado_PLC_2026-09-28.md (comparacao, verificacao e
    riscos em aberto). BOM e PDF do esquematico regenerados.
    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
    [03_alimentacao.kicad_sch, IC2S-EBM7-2608-V2.3-MOSFET.kicad_pcb]
2026-09-28 C61 2,2 uF na saida do U8 (SPX3819), como a saida do SPX da V2.2 em campo
    - Mesmo complemento da fixa (datasheet SPX3819 Fig. 18). PCB: clone do C48 a 3 mm do U8.
    - ERC 0; DRC 0 erros, sem avisos novos, paridade 1 (C35, anterior).
    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
    [03_alimentacao.kicad_sch, IC2S-EBM7-2608-V2.3-MOSFET.kicad_pcb]
